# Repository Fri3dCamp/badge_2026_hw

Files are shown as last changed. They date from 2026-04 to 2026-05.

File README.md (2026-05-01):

# Badge 2026 hardware
In deze Git repository kan je de ontwerpbestanden en productiedata vinden van de [Fri3d Camp](https://fri3d.be/) 2026 badge. Revisie 02 is de versie die op kamp zal uitgedeeld worden.

Het schema kan je terug vinden in de [revisie 02 map](<Fri3d_2026_Badge_02/OUTPUT/Fri3D Badge 2026_02.PDF>).

De badge is gebouwd rond de **Espressif [ESP32-S3-WROOM-1-N16R8](Datasheets/esp32-s3-wroom-1_wroom-1u_datasheet_en.pdf) module** met :

- 16MB flash 
- 8MB PSRAM. 
- De [ESP32-S3](Datasheets/esp32-s3_datasheet_en.pdf) dual-core Xtensa LX7 microcontroller (geklokt aan 240MHz)
- Wi-Fi (via de ESP32-S3)
- Bluetooth 5 (via de ESP32-S3)

Omdat deze microcontroller zelf een USB interface heeft is er geen nood meer om een USB serial brug te voorzien zoals op de [badge van 2022]( https://github.com/Fri3dCamp/badge-2020) en de [badge van 2018]( https://github.com/Fri3dCamp/badge). 

We hebben de badge ook uitgerust met:

- [6-assige IMU van ST](Datasheets/lsm6dso.pdf) met dank aan [EBV](https://my.avnet.com/ebv/)
- buzzer
- veel drukknoppen
- joystick
- microSD kaart lezer
- prachtige [2” IPS LCD met touchscreen](Datasheets/HXR20062C21.pdf)
- audio in- en uitgang in de vorm van een 3.5mm TRRS jack
- [extra microcontroller](Datasheets/CH32X035DS0.PDF) voor meer IO
- optionele [LoRa module](https://www.seeedstudio.com/Wio-SX1262-Wireless-Module-without-IPEX-Tape-Reel-p-6417.html)

Er is opnieuw een [tweede voeding](Datasheets/xc6210.pdf) geplaatst om de Wi-Fi module afzonderlijk van voeding te voorzien. Om energie te besparen kan je deze uitschakelen, enkel de ESP32-S3 en de board controller zullen dan nog stroom krijgen. 

Om het geheel van stroom te voorzien gebruiken we deze keer een [2000mAh lithium polymeer cel](Datasheets/2000mAh_704060_battery_Tewaycell.pdf) met een ingebouwd beschermingscircuit. Deze batterijen zijn mechanisch niet zo sterk als de 18650 cellen die we in vorige editie gebruikten, daarom heeft de badge standaard een cover om de batterij te beschermen. 

Om de batterij op te laden via de ingebouwde USB-C poort, maken we opnieuw gebruik van de [TP4056 lineaire lader](Datasheets/TP4056.pdf). 

Er is ook een aansluiting voor de [blaster van 2024]( https://github.com/Fri3dCamp/blaster_2024) ([die van 2022]( https://github.com/Fri3dCamp/timeblaster-2020) is ook compatibel met deze badge!). 

We hebben plek voorzien voor een [SAO header]( https://hackaday.com/2019/03/20/introducing-the-shitty-add-on-v1-69bis-standard/) en is er onderaan een eigen uitbreidingsconnector waar je makkelijk een draadje in kan steken om te experimenteren.

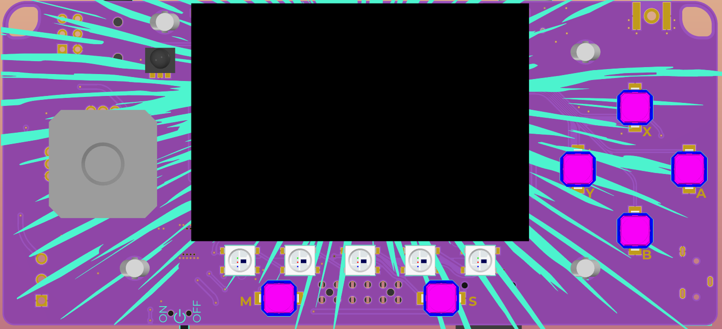
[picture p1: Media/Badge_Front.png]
Badge 2026 02 Front


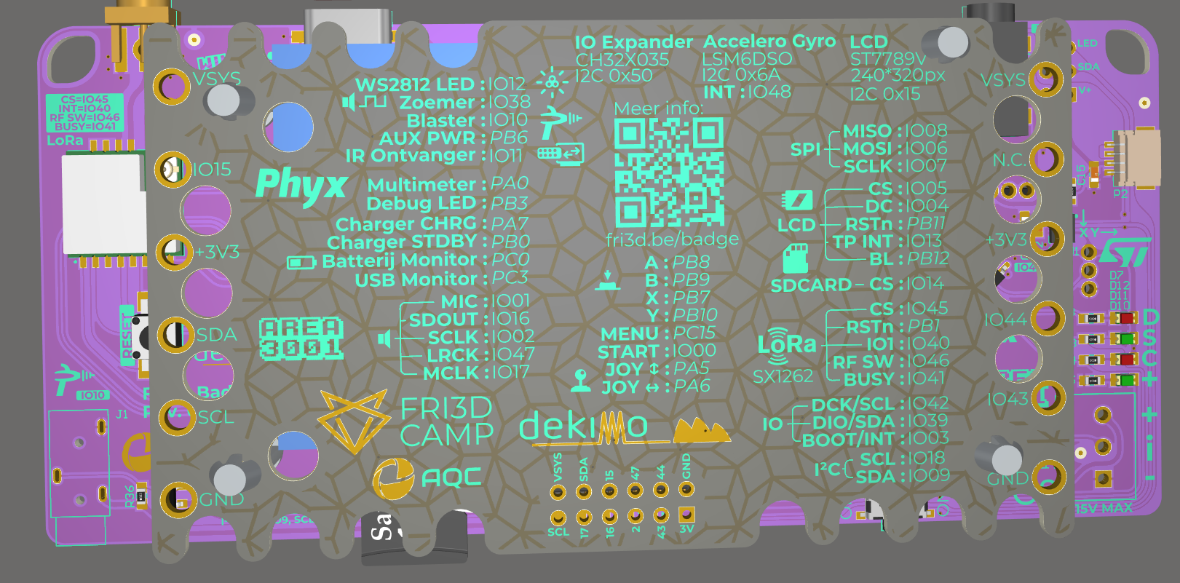
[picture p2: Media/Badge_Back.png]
Badge 2026 02 Back


Voor de liefhebbers heeft Yvan Barbaix ook een 3D model gemaakt om de joystick wat gebruiksvriendelijker te maken. Deze kan je terugvinden in de `Mechanical` map. Verder kan je het 3D model van de badge en cover ook terugvinden in [deze map](Mechanical/).

Het blokschema van de badge geeft tevens een mooi overzicht hoe alles verbonden is met elkaar, dit is een vereenvoudigde weergave van [het schema](<Fri3d_2026_Badge_02/OUTPUT/Fri3D Badge 2026_02.PDF>).

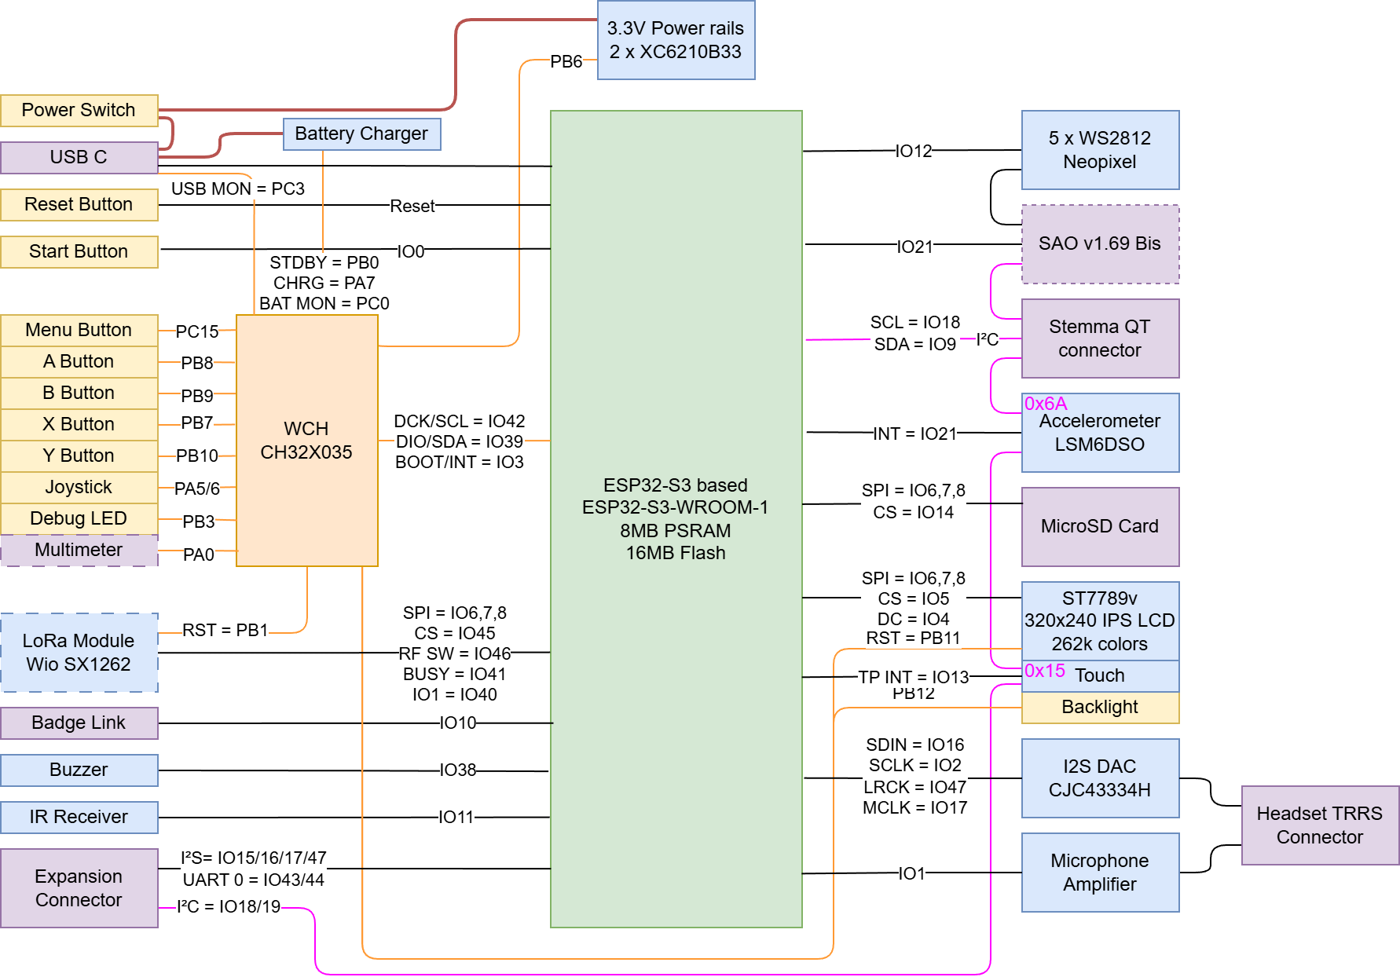
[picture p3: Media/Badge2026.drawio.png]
Badge 2026 02 Block diagram


# Badge 2026 hardware (EN)
This repository contains the hardware design and production files for the [Fri3d Camp](https://fri3d.be/en/) 2024 badge.
Revision 02 will be handed out during the event.

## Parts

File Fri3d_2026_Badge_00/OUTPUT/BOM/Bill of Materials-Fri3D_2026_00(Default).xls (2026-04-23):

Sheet: BOM Report
Bill of Materials |  |  | Fri3D Badge 2026
Project: |  | Fri3D_2026_00.PrjPcb
Revision: |  | 00
Variant: |  | Default
Creation Date: | 19/12/2025 | 22:16
Print Date: | 2026-01-17 | 22:17:15
Footprint | Comment | LibRef | Designator | Value | Description | Supplier 1 | Supplier Part Number 1 | Supplier 2 | Supplier Part Number 2 | Supplier 3 | Supplier Part Number 3 | Quantity
CUI_CMT-1203-SMT | 12x12x3mm Piezo Buzzer Transducer 81dB | BUZ # CUI CMT-1203-SMT | BUZ1 | CMT-1203-SMT | BUZ # CUI CMT-1203-SMT | Digi-key | 102-2197-1-ND | LCSC | C409829 | LCSC | C391037 | 1
C0805_N |  | CAP # 10uF 10V 0805 | C1, C10, C16, C17, C23, C24, C25 | 10uF 10V | CAP # 10uF 10V 0805 | Farnell | 2320859 | LCSC | C17024 | Generic | 10uF 10V 0805 X7R | 7
C0603_N |  | CAP # 100nF 16V 0603 | C2, C4, C6, C8, C9, C14, C15, C22 | 100nF 16V | CAP # 100nF 16V 0603 | LCSC | C282519 |  |  | Generic | 100nF 16V 0603 X7R | 8
C0603_N |  | CAP # 1uF 16V 0603 | C5, C11, C12, C13, C18, C20, C21 | 1uF 16V | CAP # 1uF 16V 0603 | Farnell | 2320814 | LCSC | C1592 | Generic | 1uF 16V 0603 X7R | 7
LED_5050_WS2812B_WHITE | WS2812 based digital RGB LED 5050 White package reduced current | LED # RGB WS2812C-5050 WH | D1, D2, D3, D4, D5 | WS218C 5050 WH | LED # RGB WS2812C-5050 WH | Aliexpress | WS2812C Black 5050 | LCSC | C114587 |  |  | 5
LED_0805_RD | Default 0805 Red LED | LED # Red 0805 | D7, D11 |  | LED # Red 0805 | Farnell | 2099236 | LCSC | C965812 |  |  | 2
LED_0805_GR | Default 0805 Green LED | LED # Green 0805 | D10, D12 |  | LED # Green 0805 | Farnell | 2099239 | LCSC | C965815 |  |  | 2
DO-214AC_AC | 40V 2A 550mV@2A DO-214 Schottky | Schottky # SS24-MS | D13 | SS24-MS | Schottky # SS24-MS | LCSC | C2836395 |  |  |  |  | 1
CHAU_ZIRM-5042B-42-Z2 | ZIRM-5042B-42-Z2 Infrared Receiver 38 kHz 45° 2.7-5.5V 940nm | PHO # IR Rx 940nm ZIRM-5042B-42-Z2 | D15 | ZIRM-5042B-42-Z2 | PHO # IR Rx 940nm ZIRM-5042B-42-Z2 | LCSC | C575386 |  |  |  |  | 1
XUNPU-TYPEC-304S-ACP16 | USB 2.0 C Reversible Receptacle Horizontal full SMD | USB # C 2.0 RCPT TYPEC-304S-ACP16 | J2 | TYPEC-304S-ACP16 | USB # C 2.0 RCPT TYPEC-304S-ACP16 | LCSC | C5187472 | LCSC | C2927040 | LCSC | C5156603 | 1
TFP09-2-12B | Micro SD PiPo Push-Push | MicroSD TFP09-2-12B Push-Push | J3 | TFP09-2-12B | MicroSD TFP09-2-12B Push-Push | AliExpress | TFP09-2-12B | LCSC | C393941 | LCSC | C381082 | 1
HC-PJ-313E8-B-SMT | 3.5mm jack, black, 4 contacts | AUDIO JACK # 3.5 4c HC-PJ-313E8-B-SMT | J4 | HC-PJ-313E8-B-SMT | AUDIO JACK # 3.5 4c HC-PJ-313E8-B-SMT | LCSC | C7501803 |  |  |  |  | 1
WE_709622400 | HIWA LCC-12 Snap-in - Snap-in 12.7mm | SPACER SNAP-SNAP LCC-12 -12.7mm | M1, M2, M3, M4 | LCC-12 | SPACER SNAP-SNAP LCC-12 -12.7mm | LCSC | C155856 |  |  |  |  | 4
FID_0.5mm | Fiducial 0.5mm | Fiducial 0.5mm | M5, M6, M7 | NO BOM | Fiducial 0.5mm | XXX | FOOTPRINT ONLY |  |  |  |  | 3
ESP-ESP32-S3-WROOM-1 | ESP32-S3 based WROOM-1 16MB Flash, 8MB PSRAM | WiFi # MOD ESP32-S3-WROOM-1-N16R8 | MOD1 | ESP32-S3-WROOM-1-N16R8 | WiFi # MOD ESP32-S3-WROOM-1-N16R8 | Espressif | ESP32-S3-WROOM-1-N16R8 | Digi-key | 1965-ESP32-S3-WROOM-1-N16R8DKR-ND |  |  | 1
HRS_FH35C-21S-0.3SHW | FH35C-21S-0.3SHW Top and Bottom Contacts 0.3mm 21pin | ZIF # 0.3mm 21p FH35C-21S-0.3SHW(50) | P1 | FH35C-21S-0.3SHW(50) | ZIF # 0.3mm 21p FH35C-21S-0.3SHW(50) | LCSC | C5242964 | Digi-key | 26-FH35C-21S-0.3SHW(50)CT-ND | LCSC | C48688891 | 1
WE_665104131822 | Header 1.0mm RA Shrouded 4 | HDR # RA SHR 1.0mm 4way - 665104131822 | P2 | 665104131822 | HDR # RA SHR 1.0mm 4way - 665104131822 | Wurth | 665104131822 | Mouser | 710-665104131822 | LCSC | C2905006 | 1
JST_ZH_S2B-ZR-SM4A-TF | Header RA 1.5mm Shrouded S2B-ZR-SM4A-TF | HDR # RA SHR 1.5mm 2way - S2B-ZR-SM4A-TF | P4 | S2B-ZR-SM4A-TF | HDR # RA SHR 1.5mm 2way - S2B-ZR-SM4A-TF | LCSC | C265329 | Farnell | 1830920 | Digi-Key | 455-1693-1-ND | 1
WE_691103110003 | 3 Way Screw HDR 3.5mm Rising Cage | Terminal Block 3.5mm 3way | P5 |  | Terminal Block 3.5mm 3way | LCSC | C784941 | Würth | 691214110003 |  |  | 1
PSP_Mini_Joystick | PSP Mini Joystick | JOY # PSP Mini Joystick | P7 | PSP Mini Joystick | JOY # PSP Mini Joystick | AliExpress | 32958017132 | TaoBao | 606257885046 |  |  | 1
WE_610312243021_POST | Receptacle 6x2 SMD low profile | Receptacle # 2.54mm dual row 12way 610312243021 | P10 | 610312243021 | Receptacle # 2.54mm dual row 12way 610312243021 | Wurth | 610312243021 | Mouser | 710-610312243021 |  |  | 1
R0603_N |  | RES # 10K 0603 | R1, R14, R15, R18, R19, R20, R30, R32, R40 | 10K | RES # 10K 0603 | Farnell | 2502397 | LCSC | C25804 | Generic | 10K 1% 0603 | 9
R0603_N |  | RES # 5K1 0603 | R2, R4, R7, R8, R9, R10, R16, R21, R23, R24, R35, R36, R37, R38, R41, R42, R50, R51 | 5K1 | RES # 5K1 0603 | Farnell | 2845922 | LCSC | C112314 | Generic | 5K1 1% 0603 | 18
R0603_N |  | RES # 100K 0603 | R3, R5, R12, R17, R25, R26, R28, R29, R33, R34 | 100K | RES # 100K 0603 | LCSC | C25803 | LCSC | C14675 | Generic | 100K 1% 0603 | 10
R0603_N |  | RES # 100R 0603 | R6, R43, R46 | 100R | RES # 100R 0603 | Farnell | 2446544 | LCSC | C22775 | Generic | 100R 1% 0603 | 3
R0603_N |  | RES # 1K5 0603 | R11, R13, R22, R31, R39 | 1K5 | RES # 1K5 0603 | LCSC | C2930050 | LCSC | C114668 | Generic | 1K5 1% 0603 | 5
R0402 |  | NTC # 10K 0402 | R27 | 10K | NTC # 10K 0402 | LCSC | C209959 | LCSC | C98099 |  |  | 1
R0603_N |  | RES # 0R 0603 | R47, R48, R49 | 0R | RES # 0R 0603 | Farnell | 2447743 | LCSC | C95177 / C15402 | Generic | 0R 1% 0603 | 3
WE_450404015514 | WS-SLSU Mini slide switch 1P2T SMD | SW # 1P2T WS-SLSU mini slide 6,7 x 2,7 mm | SW4 | 450404015514 | SW # 1P2T WS-SLSU mini slide 6,7 x 2,7 mm | Digi-key | 732-13665-1-ND | LCSC | C431540 |  |  | 1
ALPS_SKPMAME010 | SKPMAME010 6x6 TACTG Switch | SW # TACT ALPS SKPMAME010 | SW5, SW6, SW7, SW8, SW9, SW10 | SKPMAME010 | SW # TACT ALPS SKPMAME010 | LCSC | C115348 | Farnell | 2056804 | Mouser | 688-SKPMAM | 6
WE_430181038816 | 4.5x4.5mm tact SMD H3,8mm | SW # TACT small 4.5x4.5mm SMD WS-TASV | SW11 | 430181038816 | SW # TACT small 4.5x4.5mm SMD WS-TASV | Wurth | 430181038816 | Mouser | 710-430181038816 | LCSC | C174049 | 1
SOT23-3 | 0.2A N-Ch MOSFET Vgs 3.2 | BSS138 N-Ch MOSFET 0.2A 3.2Vgs 60Vds | T1, T2, T9 | BSS138 |  | Farnell | 2432717 |  |  |  |  | 3
SOT23-3 | -2.3A -20V P-Ch MOSFET Vgs -1V | SL2301 P-Ch MOSFET -2.3A -20Vds | T6, T7 | SL2301 | SL2301 P-Ch MOSFET -2.3A -20Vds | LCSC | C181086 |  |  |  |  | 2
STM_LGA14_2.5x3 | Acceleration ±2, ±4, ±8, ±16g Gyro ±125, ±250, ±500, ±1000, ±2000dps | ACCELERO GYRO # LSM6DSOTR-C | U1 | LSM6DSOTR-C | ACCELERO GYRO # LSM6DSOTR-C | LCSC | C2655100 | Mouser | 511-LSM6DSOTR | EBV | LSM6DSOTR | 1
QFN_28_4.0x4.0_P0.4 | WCH CH32X035G8U6 QFN28 RISC-V 32-bit MCU, 62KB Flash, 10KB RAM, USB PD | RISCV # CH32X035G8U6 | U2 | CH32X035G8U6 | RISCV # CH32X035G8U6 | LCSC | C7437027 |  |  |  |  | 1
SOIC_N_8 | I²S 24bit 192kHz 3V~3.6V DAC | DAC # I2S CJC4334H | U4 | CJC4334H | DAC # I2S CJC4334H | LCSC | C41417670 |  |  |  |  | 1
SOIC_N_8_TH | Single Cell LiIon charger max 1A | CHG # TP4056 LiIon 1A | U5 | TP4056 | CHG # TP4056 LiIon 1A | Aliexpress | TP4056 | LCSC | C382139 |  |  | 1
SOT23-5 | 3V3 LDO 700mA 50mV | LDO # 3V3 XC6210B33 | U6, U7 | XC6210B332MR | LDO # 3V3 XC6210B33 | Farnell | 1057803 | LCSC | C47719 |  |  | 2
TI_DBV_R-PDSO-G5 | Single, 30-V, 1-MHz operational amplifier | OP # LM321 | U8 | LM321 | OP # LM321 | LCSC | C18164494 | LCSC | C51026323 | LCSC | C18723612 | 1
 |  |  |  |  |  |  |  |  |  |  |  | 120
Approved |  | Notes

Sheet: MANUAL
LibRef | Designator | Description | QTY | 10
BUZ # CUI CMT-1203-SMT | BUZ1 | BUZ # CUI CMT-1203-SMT | 1 | 10
CAP # 10uF 10V 0805 | C1, C10, C16, C17, C23, C24, C25 | CAP # 10uF 10V 0805 | 7 | 70
CAP # 100nF 16V 0603 | C2, C4, C6, C8, C9, C14, C15, C22 | CAP # 100nF 16V 0603 | 8 | 80
CAP # 1uF 16V 0603 | C5, C11, C12, C13, C18, C20, C21 | CAP # 1uF 16V 0603 | 7 | 70
LED # RGB WS2812C-5050 WH | D1, D2, D3, D4, D5 | LED # RGB WS2812C-5050 WH | 5 | 50
LED # Red 0805 | D7, D11 | LED # Red 0805 | 2 | 20
LED # Green 0805 | D10, D12 | LED # Green 0805 | 2 | 20
Schottky # SS24-MS | D13 | Schottky # SS24-MS | 1 | 10
PHO # IR Rx 940nm ZIRM-5042B-42-Z2 | D15 | PHO # IR Rx 940nm ZIRM-5042B-42-Z2 | 1 | 10
USB # C 2.0 RCPT TYPEC-304S-ACP16 | J2 | USB # C 2.0 RCPT TYPEC-304S-ACP16 | 1 | 10
MicroSD # TFP09-2-12B Push-Push | J3 | MicroSD # TFP09-2-12B Push-Push | 1 | 10
AUDIO JACK # 3.5 4c HC-PJ-313E8-B-SMT | J4 | AUDIO JACK # 3.5 4c HC-PJ-313E8-B-SMT | 1 | 10
WiFi # MOD ESP32-S3-WROOM-1-N16R8 | MOD1 | WiFi # MOD ESP32-S3-WROOM-1-N16R8 | 1 | 10
ZIF # 0.3mm 21p FH35C-21S-0.3SHW(50) | P1 | ZIF # 0.3mm 21p FH35C-21S-0.3SHW(50) | 1 | 10
HDR # RA SHR 1.0mm 4way - 665104131822 | P2 | HDR # RA SHR 1.0mm 4way - 665104131822 | 1 | 10
HDR # RA SHR 1.5mm 2way - S2B-ZR-SM4A-TF | P4 | HDR # RA SHR 1.5mm 2way - S2B-ZR-SM4A-TF | 1 | 10
Terminal Block 3.5mm 3way | P5 | Terminal Block 3.5mm 3way | 1 | 10
JOY PSP Mini Joystick | P7 | JOY PSP Mini Joystick | 1 | 10
Receptacle # 2.54mm dual row 12way 610312243021 | P10 | Receptacle # 2.54mm dual row 12way 610312243021 | 1 | 10
RES # 10K 0603 | R1, R14, R15, R18, R19, R20, R30, R32, R40 | RES # 10K 0603 | 9 | 90
RES # 5K1 0603 | R2, R4, R7, R8, R9, R10, R16, R21, R23, R24, R35, R36, R37, R38, R41, R42, R50, R51 | RES # 5K1 0603 | 18 | 180
RES # 100K 0603 | R3, R5, R12, R17, R25, R26, R28, R29, R33, R34 | RES # 100K 0603 | 10 | 100
RES # 100R 0603 | R6, R43, R46 | RES # 100R 0603 | 3 | 30
RES # 1K5 0603 | R11, R13, R22, R31, R39 | RES # 1K5 0603 | 5 | 50
NTC # 10K 0402 | R27 | NTC # 10K 0402 | 1 | 10
RES # 0R 0603 | R47, R48, R49 | RES # 0R 0603 | 3 | 30
SW # 1P2T WS-SLSU mini slide 6,7 x 2,7 mm | SW4 | SW # 1P2T WS-SLSU mini slide 6,7 x 2,7 mm | 1 | 10
SW # TACT ALPS SKPMAME010 | SW5, SW6, SW7, SW8, SW9, SW10 | SW # TACT ALPS SKPMAME010 | 6 | 60
SW # TACT small 4.5x4.5mm SMD WS-TASV | SW11 | SW # TACT small 4.5x4.5mm SMD WS-TASV | 1 | 10
BSS138 N-Ch MOSFET 0.2A 3.2Vgs 60Vds | T1, T2, T9 |  | 3 | 30
SL2301 P-Ch MOSFET -2.3A -20Vds | T6, T7 | SL2301 P-Ch MOSFET -2.3A -20Vds | 2 | 20
ACCELERO GYRO # LSM6DSOTR-C | U1 | ACCELERO GYRO # LSM6DSOTR-C | 1 | 10
RISCV # CH32X035G8U6 | U2 | RISCV # CH32X035G8U6 | 1 | 10
DAC # I2S CJC4334H | U4 | DAC # I2S CJC4334H | 1 | 10
CHG # TP4056 LiIon 1A | U5 | CHG # TP4056 LiIon 1A | 1 | 10
LDO # 3V3 XC6210B33 | U6, U7 | LDO # 3V3 XC6210B33 | 2 | 20
OP # LM321 | U8 | OP # LM321 | 1 | 10

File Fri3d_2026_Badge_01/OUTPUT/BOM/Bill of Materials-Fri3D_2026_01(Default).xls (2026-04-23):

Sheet: BOM Report
Bill of Materials |  |  | Fri3D Badge 2026
Project: |  | Fri3D_2026_01.PrjPcb
Revision: |  | 01
Variant: |  | Default
Creation Date: | 01/03/2026 | 01:36
Print Date: | 2026-03-18 | 19:20:01
Footprint | Comment | LibRef | Designator | Value | Description | Supplier 1 | Supplier Part Number 1 | Supplier 2 | Supplier Part Number 2 | Supplier 3 | Supplier Part Number 3 | Quantity
CUI_CMT-1203-SMT | 12x12x3mm Piezo Buzzer Transducer 81dB | BUZ # CUI CMT-1203-SMT | BUZ1 | CMT-1203-SMT | BUZ # CUI CMT-1203-SMT | Digi-key | 102-2197-1-ND | LCSC | C409829 | LCSC | C391037 | 1
C0805_N |  | CAP # 10uF 10V 0805 | C1, C10, C16, C17, C23, C24, C25 | 10uF 10V | CAP # 10uF 10V 0805 | Farnell | 2320859 | LCSC | C17024 | Generic | 10uF 10V 0805 X7R | 7
C0603_N |  | CAP # 100nF 16V 0603 | C2, C4, C6, C8, C9, C14, C15, C22 | 100nF 16V | CAP # 100nF 16V 0603 | LCSC | C282519 |  |  | Generic | 100nF 16V 0603 X7R | 8
C0603_N |  | CAP # 1uF 16V 0603 | C5, C11, C12, C13, C18, C20, C21 | 1uF 16V | CAP # 1uF 16V 0603 | Farnell | 2320814 | LCSC | C1592 | Generic | 1uF 16V 0603 X7R | 7
LED_5050_WS2812B_WHITE | WS2812 based digital RGB LED 5050 White package reduced current | LED # RGB WS2812C-5050 WH | D1, D2, D3, D4, D5 | WS218C 5050 WH | LED # RGB WS2812C-5050 WH | Aliexpress | WS2812C Black 5050 | LCSC | C114587 |  |  | 5
LED_0805_RD | Default 0805 Red LED | LED # Red 0805 | D7, D11 |  | LED # Red 0805 | Farnell | 2099236 | LCSC | C965812 |  |  | 2
LED_0805_GR | Default 0805 Green LED | LED # Green 0805 | D10, D12 |  | LED # Green 0805 | Farnell | 2099239 | LCSC | C965815 |  |  | 2
DO-214AC_AC | 40V 2A 550mV@2A DO-214 Schottky | Schottky # SS24-MS | D13 | SS24-MS | Schottky # SS24-MS | LCSC | C2836395 |  |  |  |  | 1
CHAU_ZIRM-5042B-42-Z2 | ZIRM-5042B-42-Z2 Infrared Receiver 38 kHz 45° 2.7-5.5V 940nm | PHO # IR Rx 940nm ZIRM-5042B-42-Z2 | D15 | ZIRM-5042B-42-Z2 | PHO # IR Rx 940nm ZIRM-5042B-42-Z2 | LCSC | C575386 |  |  |  |  | 1
SHOU_HAN_PJ-320A-3P | 3.5mm jack, black, 3 contacts | AUDIO JACK 3.5 3c PJ-320A-3P | J1 | PJ-320A-3P | AUDIO JACK 3.5 3c PJ-320A-3P | LCSC | C17701689 | LCSC | C19189087 |  |  | 1
XUNPU-TYPEC-304S-ACP16 | USB 2.0 C Reversible Receptacle Horizontal full SMD | USB # C 2.0 RCPT TYPEC-304S-ACP16 | J2 | TYPEC-304S-ACP16 | USB # C 2.0 RCPT TYPEC-304S-ACP16 | LCSC | C5187472 | LCSC | C2927040 | LCSC | C5156603 | 1
TFP09-2-12B | Micro SD PiPo Push-Push | MicroSD TFP09-2-12B Push-Push | J3 | TFP09-2-12B | MicroSD TFP09-2-12B Push-Push | AliExpress | TFP09-2-12B | LCSC | C393941 | LCSC | C381082 | 1
CAX_PJ-327F-5PS | 3.5mm jack, black, 4 contacts 15mm | AUDIO JACK # 3.5 4c 15mm PJ-327F-5PS | J4 | PJ-327F-5PS | AUDIO JACK # 3.5 4c 15mm PJ-327F-5PS | LCSC | C50176645 |  |  |  |  | 1
WE_709622400 | HIWA LCC-12 Snap-in - Snap-in 12.7mm | SPACER SNAP-SNAP LCC-12 -12.7mm | M1, M2, M3, M4 | LCC-12 | SPACER SNAP-SNAP LCC-12 -12.7mm | LCSC | C155856 |  |  |  |  | 4
FID_0.5mm | Fiducial 0.5mm | Fiducial 0.5mm | M5, M6, M7 | NO BOM | Fiducial 0.5mm | XXX | FOOTPRINT ONLY |  |  |  |  | 3
ESP-ESP32-S3-WROOM-1 | ESP32-S3 based WROOM-1 16MB Flash, 8MB PSRAM | WiFi # MOD ESP32-S3-WROOM-1-N16R8 | MOD1 | ESP32-S3-WROOM-1-N16R8 | WiFi # MOD ESP32-S3-WROOM-1-N16R8 | Espressif | ESP32-S3-WROOM-1-N16R8 | Digi-key | 1965-ESP32-S3-WROOM-1-N16R8DKR-ND |  |  | 1
SEE_Wio-SX1262 | 868/915MHz 22dBm LoRa Module with Antenna Pin | RF # MOD Wio-SX1262-N 868MHz LoRa ANT pin | MOD2 | Wio-SX1262-N | RF # MOD Wio-SX1262-N 868MHz LoRa ANT pin | Seeed Studio | 113991436 | Digi-key | 1597-113991436-ND |  |  | 1
HRS_FH35C-21S-0.3SHW | FH35C-21S-0.3SHW Top and Bottom Contacts 0.3mm 21pin | ZIF # 0.3mm 21p FH35C-21S-0.3SHW(50) | P1 | FH35C-21S-0.3SHW(50) | ZIF # 0.3mm 21p FH35C-21S-0.3SHW(50) | LCSC | C5242964 | Digi-key | 26-FH35C-21S-0.3SHW(50)CT-ND | LCSC | C48688891 | 1
WE_665104131822 | Header 1.0mm RA Shrouded 4 | HDR # RA SHR 1.0mm 4way - 665104131822 | P2 | 665104131822 | HDR # RA SHR 1.0mm 4way - 665104131822 | Wurth | 665104131822 | Mouser | 710-665104131822 | LCSC | C2905006 | 1
DEA_DL-SMA-K513-08K | DEALON DL-SMA-K513-08K | RF # SMA DL-SMA-K513-08K | P3 | DL-SMA-K513-08K | RF # SMA DL-SMA-K513-08K | LCSC | C4749212 |  |  |  |  | 1
JST_ZH_S2B-ZR-SM4A-TF | Header RA 1.5mm Shrouded S2B-ZR-SM4A-TF | HDR # RA SHR 1.5mm 2way - S2B-ZR-SM4A-TF | P4 | S2B-ZR-SM4A-TF | HDR # RA SHR 1.5mm 2way - S2B-ZR-SM4A-TF | LCSC | C265329 | Farnell | 1830920 | Digi-Key | 455-1693-1-ND | 1
WE_691103110003 | 3 Way Screw HDR 3.5mm Rising Cage | Terminal Block 3.5mm 3way | P5 |  | Terminal Block 3.5mm 3way | LCSC | C784941 | Würth | 691214110003 |  |  | 1
RCPT2X3 | Receptacle 3x2 | Receptacle 2.54mm dual row 6way | P6 |  | Receptacle 2.54mm dual row 6way | LCSC | C92272 | LCSC | C358725 |  |  | 1
PSP_Mini_Joystick | PSP Mini Joystick | JOY # PSP Mini Joystick | P7 | PSP Mini Joystick | JOY # PSP Mini Joystick | AliExpress | 32958017132 | TaoBao | 606257885046 |  |  | 1
WE_610312243021_POST | Receptacle 6x2 SMD low profile | Receptacle # 2.54mm dual row 12way 610312243021 | P10 | 610312243021 | Receptacle # 2.54mm dual row 12way 610312243021 | Wurth | 610312243021 | Mouser | 710-610312243021 |  |  | 1
R0603_N |  | RES # 10K 0603 | R1, R14, R15, R18, R19, R20, R30, R32, R40 | 10K | RES # 10K 0603 | Farnell | 2502397 | LCSC | C25804 | Generic | 10K 1% 0603 | 9
R0603_N |  | RES # 5K1 0603 | R2, R7, R8, R9, R10, R16, R21, R23, R24, R35, R36, R37, R38, R41, R42, R50, R51 | 5K1 | RES # 5K1 0603 | Farnell | 2845922 | LCSC | C112314 | Generic | 5K1 1% 0603 | 17
R0603_N |  | RES # 100K 0603 | R3, R5, R12, R17, R25, R26, R28, R29, R33, R34 | 100K | RES # 100K 0603 | LCSC | C25803 | LCSC | C14675 | Generic | 100K 1% 0603 | 10
R0603_N |  | RES # 100R 0603 | R4, R6, R43, R46 | 100R | RES # 100R 0603 | Farnell | 2446544 | LCSC | C22775 | Generic | 100R 1% 0603 | 4
R0603_N |  | RES # 1K5 0603 | R13, R22, R31, R39 | 1K5 | RES # 1K5 0603 | LCSC | C2930050 | LCSC | C114668 | Generic | 1K5 1% 0603 | 4
R0402 |  | NTC # 10K 0402 | R27 | 10K | NTC # 10K 0402 | LCSC | C209959 | LCSC | C98099 |  |  | 1
WE_450404015514 | WS-SLSU Mini slide switch 1P2T SMD | SW # 1P2T WS-SLSU mini slide 6,7 x 2,7 mm | SW4 | 450404015514 | SW # 1P2T WS-SLSU mini slide 6,7 x 2,7 mm | Digi-key | 732-13665-1-ND | LCSC | C431540 |  |  | 1
ALPS_SKPMAME010 | SKPMAME010 6x6 TACTG Switch | SW # TACT ALPS SKPMAME010 | SW5, SW6, SW7, SW8, SW9, SW10 | SKPMAME010 | SW # TACT ALPS SKPMAME010 | LCSC | C115348 | Farnell | 2056804 | Mouser | 688-SKPMAM | 6
WE_430181038816 | 4.5x4.5mm tact SMD H3,8mm | SW # TACT small 4.5x4.5mm SMD WS-TASV | SW11 | 430181038816 | SW # TACT small 4.5x4.5mm SMD WS-TASV | Wurth | 430181038816 | Mouser | 710-430181038816 | LCSC | C174049 | 1
SOT23-3 | 0.2A N-Ch MOSFET Vgs 3.2 | BSS138 N-Ch MOSFET 0.2A 3.2Vgs 60Vds | T1, T2, T9 | BSS138 |  | Farnell | 2432717 |  |  |  |  | 3
SOT23-3 | -2.3A -20V P-Ch MOSFET Vgs -1V | SL2301 P-Ch MOSFET -2.3A -20Vds | T6, T7 | SL2301 | SL2301 P-Ch MOSFET -2.3A -20Vds | LCSC | C181086 |  |  |  |  | 2
TP_1.5mm_0.9mm |  | TP 1.5mm | TP1 | NO BOM | TP 1.5mm |  |  |  |  |  |  | 1
STM_LGA14_2.5x3 | Acceleration ±2, ±4, ±8, ±16g Gyro ±125, ±250, ±500, ±1000, ±2000dps | ACCELERO GYRO # LSM6DSOTR-C | U1 | LSM6DSOTR-C | ACCELERO GYRO # LSM6DSOTR-C | LCSC | C2655100 | Mouser | 511-LSM6DSOTR | EBV | LSM6DSOTR | 1
QFN_28_4.0x4.0_P0.4 | WCH CH32X035G8U6 QFN28 RISC-V 32-bit MCU, 62KB Flash, 10KB RAM, USB PD | RISCV # CH32X035G8U6 | U2 | CH32X035G8U6 | RISCV # CH32X035G8U6 | LCSC | C7437027 |  |  |  |  | 1
SOIC_N_8 | I²S 24bit 192kHz 3V~3.6V DAC | DAC # I2S CJC4334H | U4 | CJC4334H | DAC # I2S CJC4334H | LCSC | C41417670 |  |  |  |  | 1
SOIC_N_8_TH | Single Cell LiIon charger max 1A | CHG # TP4056 LiIon 1A | U5 | TP4056 | CHG # TP4056 LiIon 1A | Aliexpress | TP4056 | LCSC | C382139 |  |  | 1
SOT23-5 | 3V3 LDO 700mA 50mV | LDO # 3V3 XC6210B33 | U6, U7 | XC6210B332MR | LDO # 3V3 XC6210B33 | Farnell | 1057803 | LCSC | C47719 |  |  | 2
TI_DBV_R-PDSO-G5 | Single, 30-V, 1-MHz operational amplifier | OP # LM321 | U8 | LM321 | OP # LM321 | LCSC | C18164494 | LCSC | C51026323 | LCSC | C18723612 | 1
 |  |  |  |  |  |  |  |  |  |  |  | 121
Approved |  | Notes

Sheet: Print
Footprint | Designator | Description | Quantity
CUI_CMT-1203-SMT | BUZ1 | BUZ # CUI CMT-1203-SMT | 1
C0805_N | C1, C10, C16, C17, C23, C24, C25 | CAP # 10uF 10V 0805 | 7
C0603_N | C2, C4, C6, C8, C9, C14, C15, C22 | CAP # 100nF 16V 0603 | 8
C0603_N | C5, C11, C12, C13, C18, C20, C21 | CAP # 1uF 16V 0603 | 7
LED_5050_WS2812B_WHITE | D1, D2, D3, D4, D5 | LED # RGB WS2812C-5050 WH | 5
LED_0805_RD | D7, D11 | LED # Red 0805 | 2
LED_0805_GR | D10, D12 | LED # Green 0805 | 2
DO-214AC_AC | D13 | Schottky # SS24-MS | 1
CHAU_ZIRM-5042B-42-Z2 | D15 | PHO # IR Rx 940nm ZIRM-5042B-42-Z2 | 1
SHOU_HAN_PJ-320A-3P | J1 | AUDIO JACK 3.5 3c PJ-320A-3P | 1
XUNPU-TYPEC-304S-ACP16 | J2 | USB # C 2.0 RCPT TYPEC-304S-ACP16 | 1
TFP09-2-12B | J3 | MicroSD TFP09-2-12B Push-Push | 1
CAX_PJ-327F-5PS | J4 | AUDIO JACK # 3.5 4c 15mm PJ-327F-5PS | 1
WE_709622400 | M1, M2, M3, M4 | SPACER SNAP-SNAP LCC-12 -12.7mm | 4
FID_0.5mm | M5, M6, M7 | Fiducial 0.5mm | 3
ESP-ESP32-S3-WROOM-1 | MOD1 | WiFi # MOD ESP32-S3-WROOM-1-N16R8 | 1
SEE_Wio-SX1262 | MOD2 | RF # MOD Wio-SX1262-N 868MHz LoRa ANT pin | 1
HRS_FH35C-21S-0.3SHW | P1 | ZIF # 0.3mm 21p FH35C-21S-0.3SHW(50) | 1
WE_665104131822 | P2 | HDR # RA SHR 1.0mm 4way - 665104131822 | 1
DEA_DL-SMA-K513-08K | P3 | RF # SMA DL-SMA-K513-08K | 1
JST_ZH_S2B-ZR-SM4A-TF | P4 | HDR # RA SHR 1.5mm 2way - S2B-ZR-SM4A-TF | 1
WE_691103110003 | P5 | Terminal Block 3.5mm 3way | 1
RCPT2X3 | P6 | Receptacle 2.54mm dual row 6way | 1
PSP_Mini_Joystick | P7 | JOY # PSP Mini Joystick | 1
WE_610312243021_POST | P10 | Receptacle # 2.54mm dual row 12way 610312243021 | 1
R0603_N | R1, R14, R15, R18, R19, R20, R30, R32, R40 | RES # 10K 0603 | 9
R0603_N | R2, R7, R8, R9, R10, R16, R21, R23, R24, R35, R36, R37, R38, R41, R42, R50, R51 | RES # 5K1 0603 | 17
R0603_N | R3, R5, R12, R17, R25, R26, R28, R29, R33, R34 | RES # 100K 0603 | 10
R0603_N | R4, R6, R43, R46 | RES # 100R 0603 | 4
R0603_N | R13, R22, R31, R39 | RES # 1K5 0603 | 4
R0402 | R27 | NTC # 10K 0402 | 1
WE_450404015514 | SW4 | SW # 1P2T WS-SLSU mini slide 6,7 x 2,7 mm | 1
ALPS_SKPMAME010 | SW5, SW6, SW7, SW8, SW9, SW10 | SW # TACT ALPS SKPMAME010 | 6
WE_430181038816 | SW11 | SW # TACT small 4.5x4.5mm SMD WS-TASV | 1
SOT23-3 | T1, T2, T9 |  | 3
SOT23-3 | T6, T7 | SL2301 P-Ch MOSFET -2.3A -20Vds | 2
TP_1.5mm_0.9mm | TP1 | TP 1.5mm | 1
STM_LGA14_2.5x3 | U1 | ACCELERO GYRO # LSM6DSOTR-C | 1
QFN_28_4.0x4.0_P0.4 | U2 | RISCV # CH32X035G8U6 | 1
SOIC_N_8 | U4 | DAC # I2S CJC4334H | 1
SOIC_N_8_TH | U5 | CHG # TP4056 LiIon 1A | 1
SOT23-5 | U6, U7 | LDO # 3V3 XC6210B33 | 2
TI_DBV_R-PDSO-G5 | U8 | OP # LM321 | 1

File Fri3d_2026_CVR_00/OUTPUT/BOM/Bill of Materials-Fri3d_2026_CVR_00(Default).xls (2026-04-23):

Bill of Materials |  |  | Fri3D Badge 2026 CVR
Project: |  | Fri3d_2026_CVR_00.PrjPcb
Revision: |  | 00
Variant: |  | Default
Creation Date: | 17/04/2026 | 22:50
Print Date: | 2026-04-17 | 22:50:30
Footprint | Comment | LibRef | Designator | #Column Name Error:' Value | Description | #Column Name Error:' Supplier 1 | #Column Name Error:' Supplier Part Number 1 | #Column Name Error:' Supplier 2 | #Column Name Error:' Supplier Part Number 2 | #Column Name Error:' Supplier 3 | #Column Name Error:' Supplier Part Number 3 | Quantity
 |  |  |  |  |  |  |  |  |  |  |  | 0
Approved |  | Notes

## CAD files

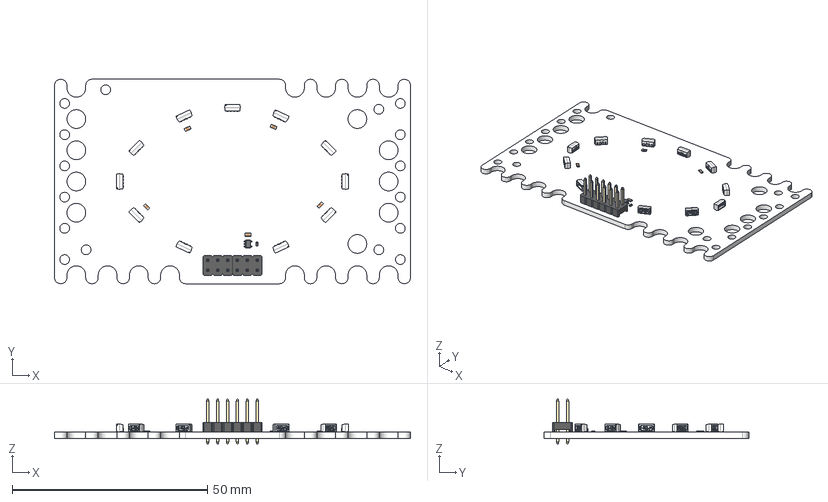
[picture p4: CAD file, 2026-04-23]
Mechanical/Fri3d_2026_CVR_00.step
91.2 x 52.4 x 11.5 mm
R0402
LED4020-ZAO x 44
LED4020-BDT x 11
LED4020 x 11
XIN-L0_2MM-CR x 11
XIN-L0_1X0_2MM-CG x 11
XIN-L0_1X0_2MM-CB x 11
C0603 x 5
User Library-SC70-5-1
HDR_2x3 x 2

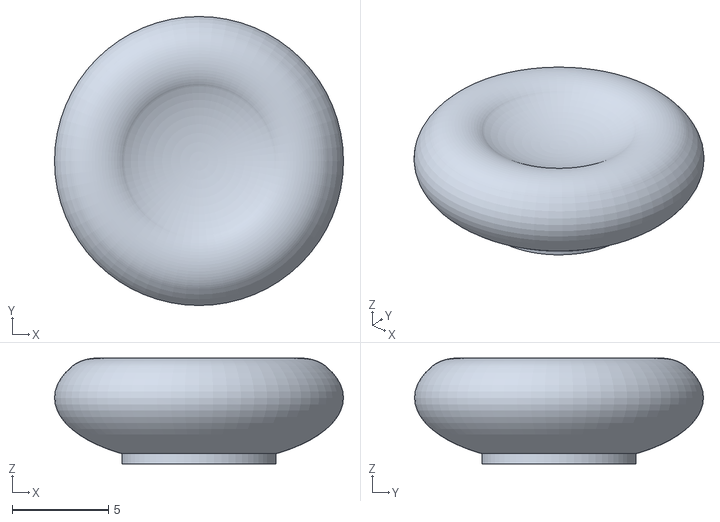
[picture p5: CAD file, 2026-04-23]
Mechanical/joystick.stl
15.0 x 15.0 x 5.50

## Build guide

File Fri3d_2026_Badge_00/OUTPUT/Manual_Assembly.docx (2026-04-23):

BADGE 2026 REV.00

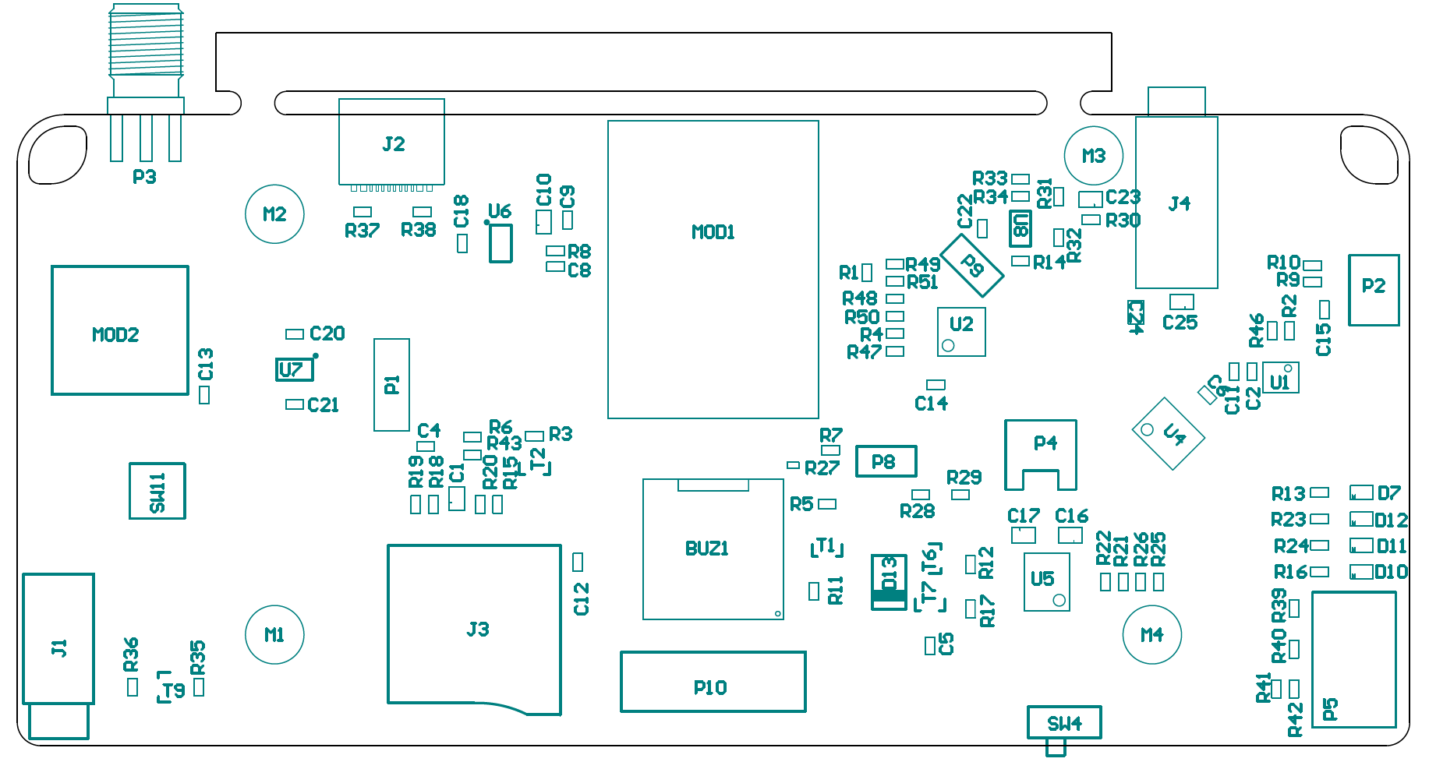
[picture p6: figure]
Afbeelding met tekst, diagram, Plan, schematisch Door AI gegenereerde inhoud is mogelijk onjuist.
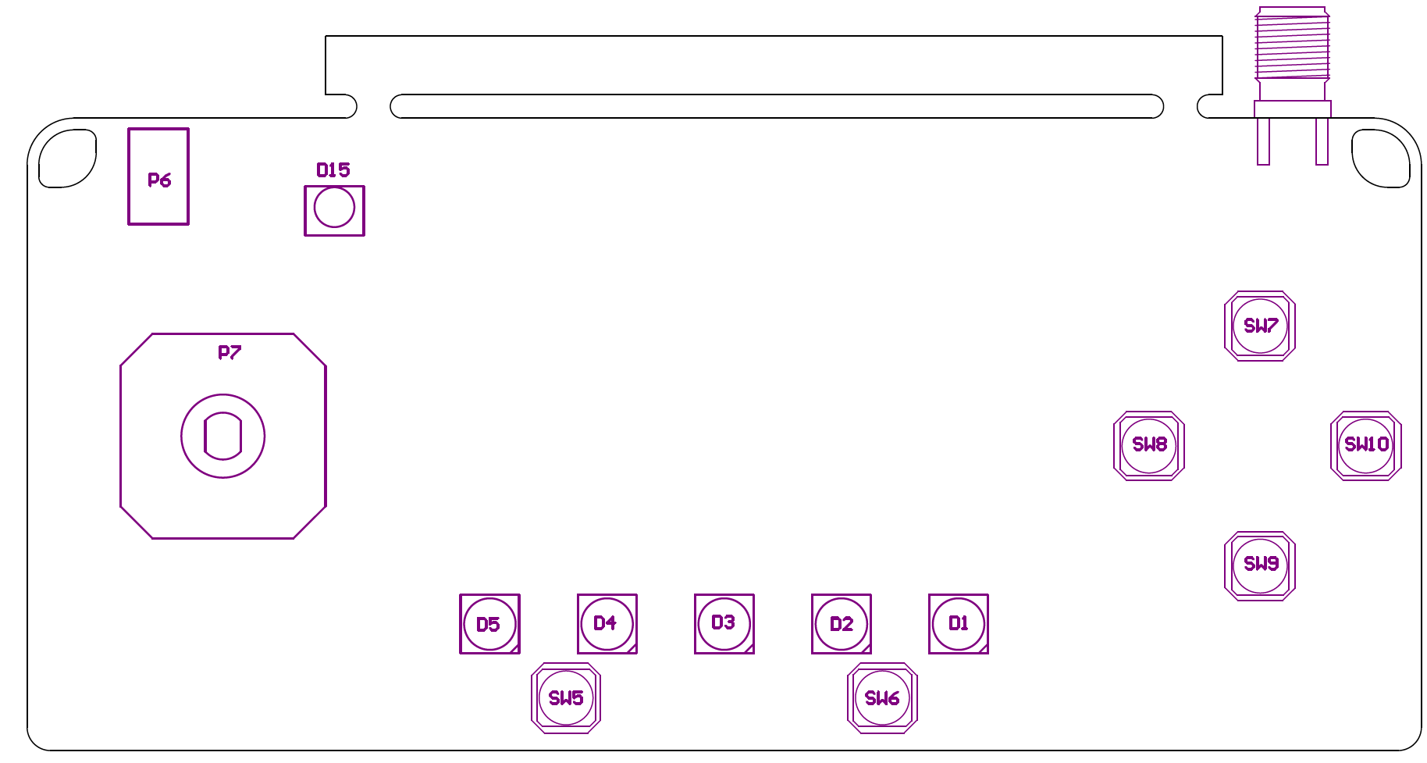
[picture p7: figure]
Afbeelding met tekst, diagram, schermopname, Rechthoek Door AI gegenereerde inhoud is mogelijk onjuist.

LibRef | Designator | Description | QTY | 10
BUZ # CUI CMT-1203-SMT | BUZ1 | BUZ # CUI CMT-1203-SMT | 1 | 10
CAP # 10uF 10V 0805 | C1, C10, C16, C17, C23, C24, C25 | CAP # 10uF 10V 0805 | 7 | 70
CAP # 100nF 16V 0603 | C2, C4, C6, C8, C9, C14, C15, C22 | CAP # 100nF 16V 0603 | 8 | 80
CAP # 1uF 16V 0603 | C5, C11, C12, C13, C18, C20, C21 | CAP # 1uF 16V 0603 | 7 | 70
LED # RGB WS2812C-5050 WH | D1, D2, D3, D4, D5 | LED # RGB WS2812C-5050 WH | 5 | 50
LED # Red 0805 | D7, D11 | LED # Red 0805 | 2 | 20
LED # Green 0805 | D10, D12 | LED # Green 0805 | 2 | 20
Schottky # SS24-MS | D13 | Schottky # SS24-MS | 1 | 10
PHO # IR Rx 940nm ZIRM-5042B-42-Z2 | D15 | PHO # IR Rx 940nm ZIRM-5042B-42-Z2 | 1 | 10
USB # C 2.0 RCPT TYPEC-304S-ACP16 | J2 | USB # C 2.0 RCPT TYPEC-304S-ACP16 | 1 | 10
MicroSD # TFP09-2-12B Push-Push | J3 | MicroSD # TFP09-2-12B Push-Push | 1 | 10
AUDIO JACK # 3.5 4c HC-PJ-313E8-B-SMT | J4 | AUDIO JACK # 3.5 4c HC-PJ-313E8-B-SMT | 1 | 10
WiFi # MOD ESP32-S3 | MOD1 | WiFi # MOD ESP32-S3-WROOM | 1 | 10
ZIF # 0.3mm 21p FH35C-21S-0.3SHW(50) | P1 | ZIF # 0.3mm 21p FH35C-21S-0.3SHW(50) | 1 | 10
HDR # RA SHR 1.0mm 4way | P2 | HDR # RA SHR 1.0mm 4way - 665104131822 | 1 | 10
HDR # RA SHR 1.5mm 2way | P4 | HDR # RA SHR 1.5mm 2way - S2B-ZR-SM4A-TF | 1 | 10
TB 3.5mm 3way | P5 | Terminal Block 3.5mm 3way | 1 | 10
JOY PSP Mini Joystick | P7 | JOY PSP Mini Joystick | 1 | 10
Receptacle # 2.54mm dual row 12way 610312243021 | P10 | Receptacle # 2.54mm dual row 12way 610312243021 | 1 | 10
RES # 10K 0603 | R1, R14, R15, R18, R19, R20, R30, R32, R40 | RES # 10K 0603 | 9 | 90
RES # 5K1 0603 | R2, R4, R7, R8, R9, R10, R16, R21, R23, R24, R35, R36, R37, R38, R41, R42, R50, R51 | RES # 5K1 0603 | 18 | 180
RES # 100K 0603 | R3, R5, R12, R17, R25, R26, R28, R29, R33, R34 | RES # 100K 0603 | 10 | 100
RES # 100R 0603 | R6, R43, R46 | RES # 100R 0603 | 3 | 30
RES # 1K5 0603 | R11, R13, R22, R31, R39 | RES # 1K5 0603 | 5 | 50
NTC # 10K 0402 | R27 | NTC # 10K 0402 | 1 | 10
RES # 0R 0603 | R47, R48, R49 | RES # 0R 0603 | 3 | 30
SW # 1P2T WS-SLSU mini slide 6,7 x 2,7 mm | SW4 | SW # 1P2T WS-SLSU mini slide 6,7 x 2,7 mm | 1 | 10
SW # TACT ALPS SKPMAME010 | SW5, SW6, SW7, SW8, SW9, SW10 | SW # TACT ALPS SKPMAME010 | 6 | 60
SW # TACT small 4.5x4.5mm | SW11 | SW # TACT small 4.5x4.5mm SMD WS-TASV | 1 | 10
BSS138 N-Ch MOSFET 0.2A 3.2Vgs 60Vds | T1, T2, T9 | | 3 | 30
SL2301 P-Ch MOSFET -2.3A -20Vds | T6, T7 | SL2301 P-Ch MOSFET -2.3A -20Vds | 2 | 20
ACCELERO GYRO # LSM6DSOTR-C | U1 | ACCELERO GYRO # LSM6DSOTR-C | 1 | 10
RISCV # CH32X035G8U6 | U2 | RISCV # CH32X035G8U6 | 1 | 10
DAC # I2S CJC4334H | U4 | DAC # I2S CJC4334H | 1 | 10
CHG # TP4056 LiIon 1A | U5 | CHG # TP4056 LiIon 1A | 1 | 10
LDO # 3V3 XC6210B33 | U6, U7 | LDO # 3V3 XC6210B33 | 2 | 20
OP # LM321 | U8 | OP # LM321 | 1 | 10

DJ-ADDON 2026 REV.00

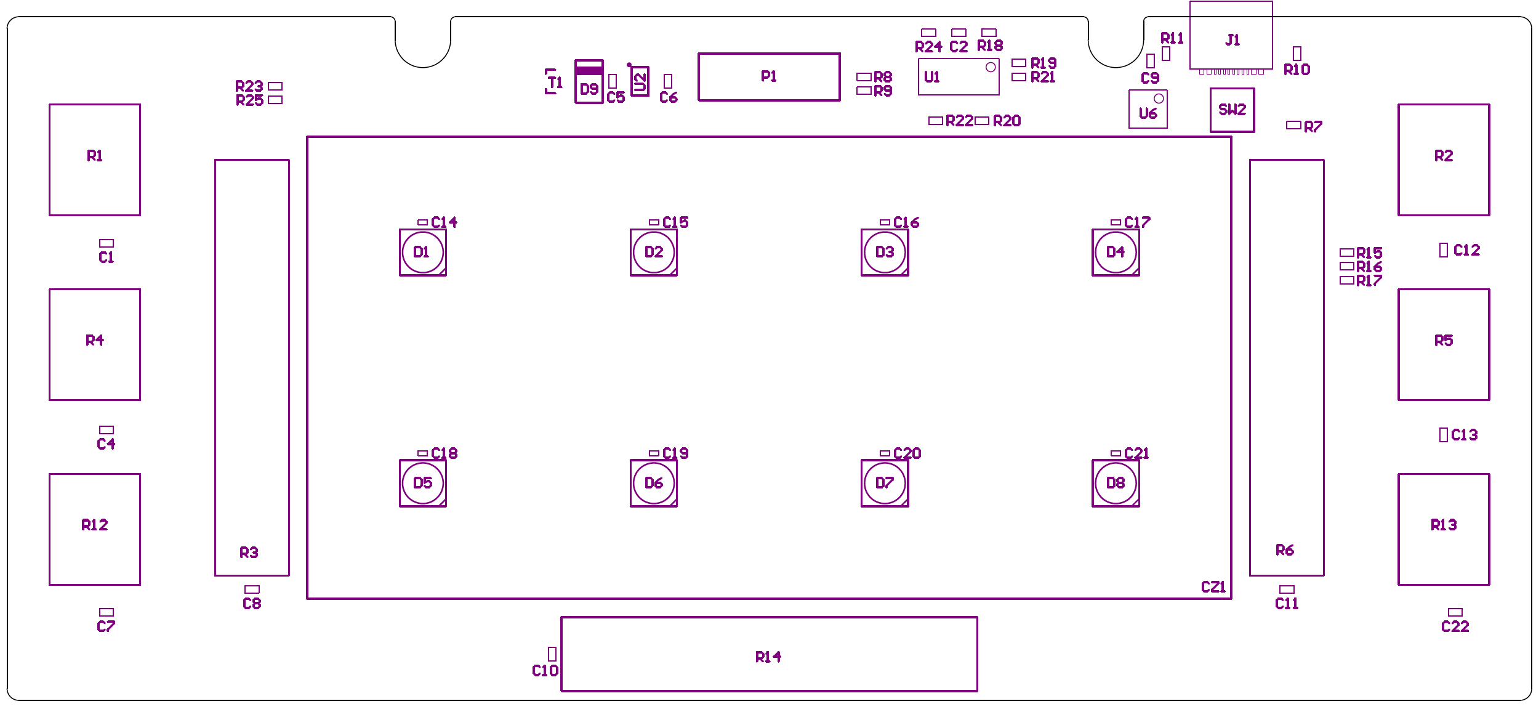
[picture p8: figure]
Afbeelding met diagram, tekst, Rechthoek, Plan Door AI gegenereerde inhoud is mogelijk onjuist.

LibRef | Designator | Description | QTY | 5
CAP # 100nF 16V 0603 | C2, C9 | CAP # 100nF 16V 0603 | 2 | 10
CAP # 1uF 16V 0603 | C5, C6 | CAP # 1uF 16V 0603 | 2 | 10
CAP # 100pF 50V 0603 | C22 | CAP # 100pF 50V 0603 | 1 | 5
SW # CZ20 2x4 | CZ1 | SW # CZ20 2x4 | 1 | 5
LED # RGB WS2812C-5050 | D1, D2, D3, D4, D5, D6, D7, D8 | LED # RGB WS2812C-5050 WH | 8 | 40
Schottky # SS24-MS | D9 | Schottky # SS24-MS | 1 | 5
USB # C 2.0 RCPT TYPEC-304S-ACP16 | J1 | USB # C 2.0 RCPT TYPEC-304S-ACP16 | 1 | 5
2.54mm dual row 12way | P1 | Pin Header 2.54mm dual row 12way | 1 | 5
Pin Header 2.54mm 3way | P2, P3 | Pin Header 2.54mm 3way | 2 | 10
RES VAR POT 10k RK09K1130AAU | R1, R2, R4, R5, R12, R13 | RES VAR POT 10k RK09K1130AAU | 6 | 30
RES VAR SLIDE 50k RS301111J00R | R3, R6, R14 | RES VAR SLIDE 50k RS301111J00R | 3 | 15
RES # 10K 0603 | R7, R15, R16, R17, R18, R20, R22, R24 | RES # 10K 0603 | 8 | 40
RES # 0R 0603 | R8, R9 | RES # 0R 0603 | 2 | 10
RES # 5K1 0603 | R10, R11 | RES # 5K1 0603 | 2 | 10
RES # 1K 0603 | R19, R21, R23, R25 | RES # 1K 0603 | 4 | 20
SW # TACT small 4.5x4.5mm SMD WS-TASV | SW2 | SW # TACT small 4.5x4.5mm SMD WS-TASV | 1 | 5
SL2301 # P-Ch MOSFET -2.3A -20Vds | T1 | SL2301 # P-Ch MOSFET -2.3A -20Vds | 1 | 5
OP # LM324 | U1 | OP # LM324 | 1 | 5
LDO # 3V3 300mA RT9078-33GJ5 | U2 | LDO # 3V3 300mA RT9078-33GJ5 | 1 | 5
RISCV # CH32X035G8U6 | U6 | RISCV # CH32X035G8U6 | 1 | 5

TOF-ADDON 2026 REV.00

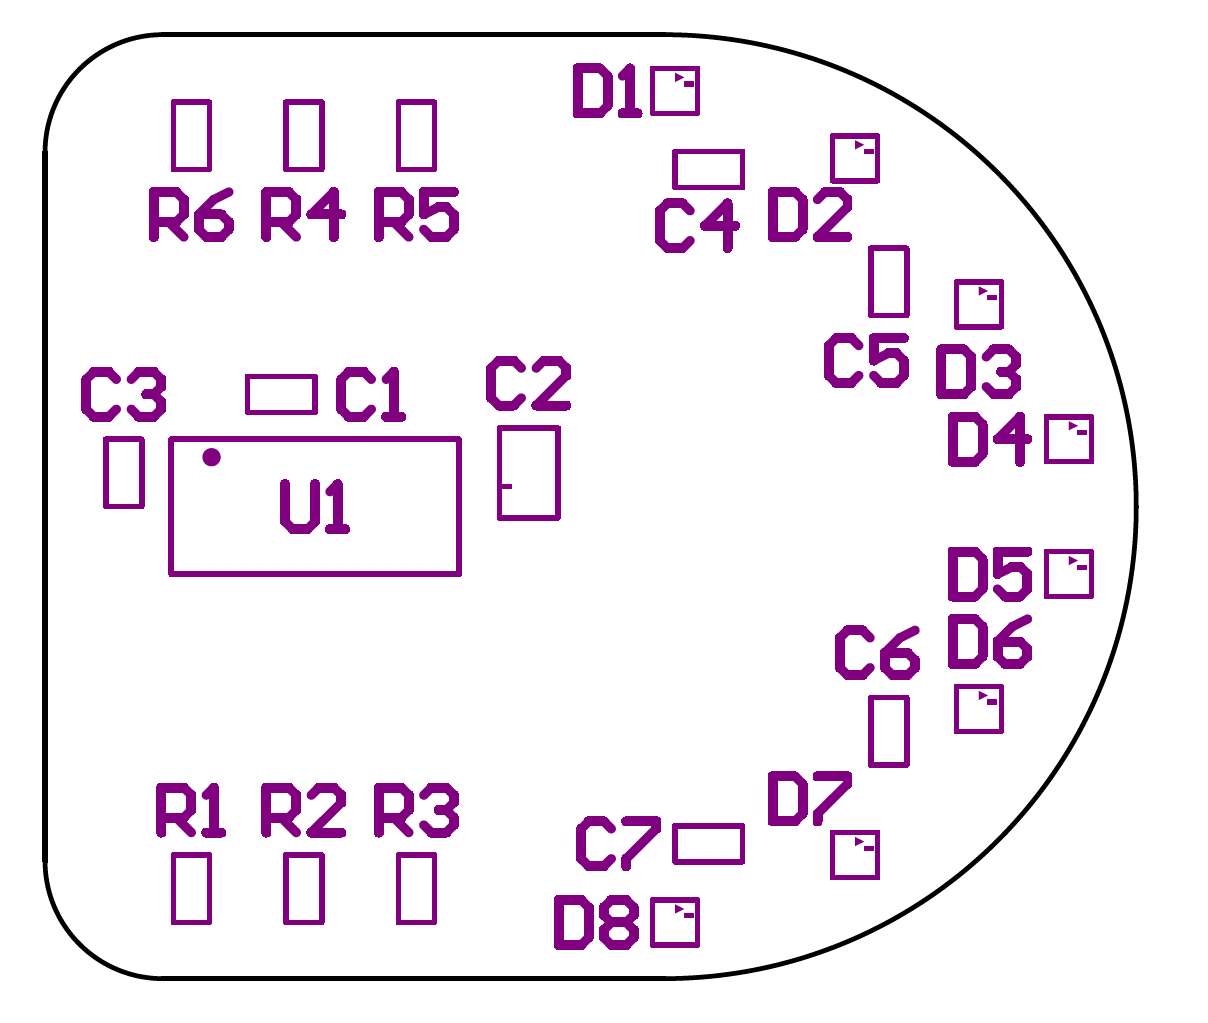
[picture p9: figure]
Afbeelding met tekst, Lettertype, diagram, schermopname Door AI gegenereerde inhoud is mogelijk onjuist.

LibRef | Designator | Description | QTY | 9
CAP # 100nF 16V 0603 | C1, C3, C4, C5, C6, C7 | CAP # 100nF 16V 0603 | 6 | 54
CAP # 10uF 10V 0805 | C2 | CAP # 10uF 10V 0805 | 1 | 9
LED # RGB XL-1010RGBC-WS2812B | D1, D2, D3, D4, D5, D6, D7, D8 | LED # RGB XL-1010RGBC-WS2812B | 8 | 72
Header dual row 6way Boxed | P1 | Header 2.54mm dual row 6 Boxed | 1 | 9
RES # 47K 0603 | R1, R4, R5, R6 | RES # 47K 0603 | 4 | 36
TOF # VL53L7CH | U1 | TOF # VL53L7CH | 1 | 9

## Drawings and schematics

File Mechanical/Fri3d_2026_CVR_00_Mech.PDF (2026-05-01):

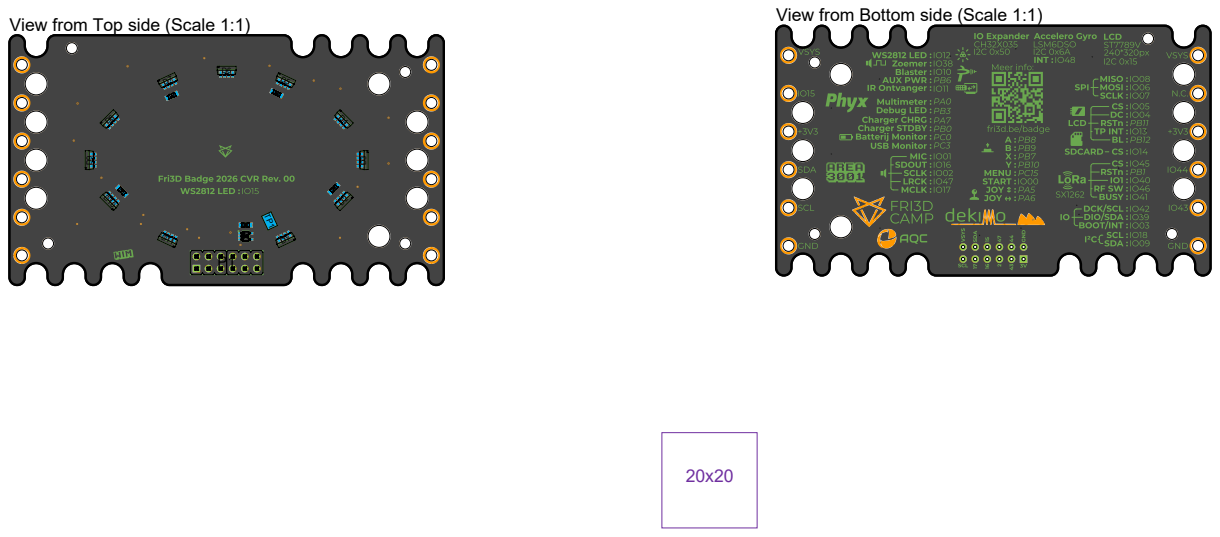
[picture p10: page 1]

View from Bottom side (Scale 1:1)

View from Top side (Scale 1:1)

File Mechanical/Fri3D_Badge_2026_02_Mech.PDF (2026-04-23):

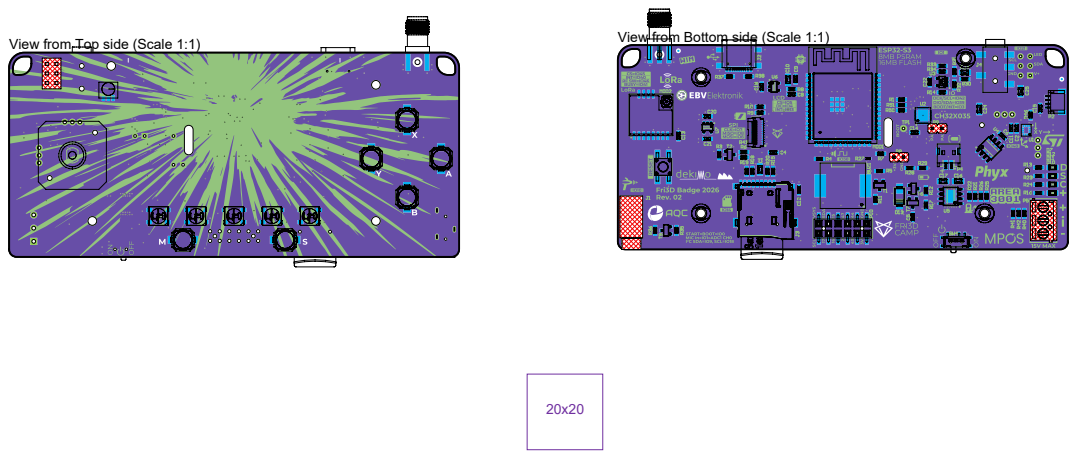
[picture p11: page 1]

View from Top side (Scale 1:1)

View from Bottom side (Scale 1:1)

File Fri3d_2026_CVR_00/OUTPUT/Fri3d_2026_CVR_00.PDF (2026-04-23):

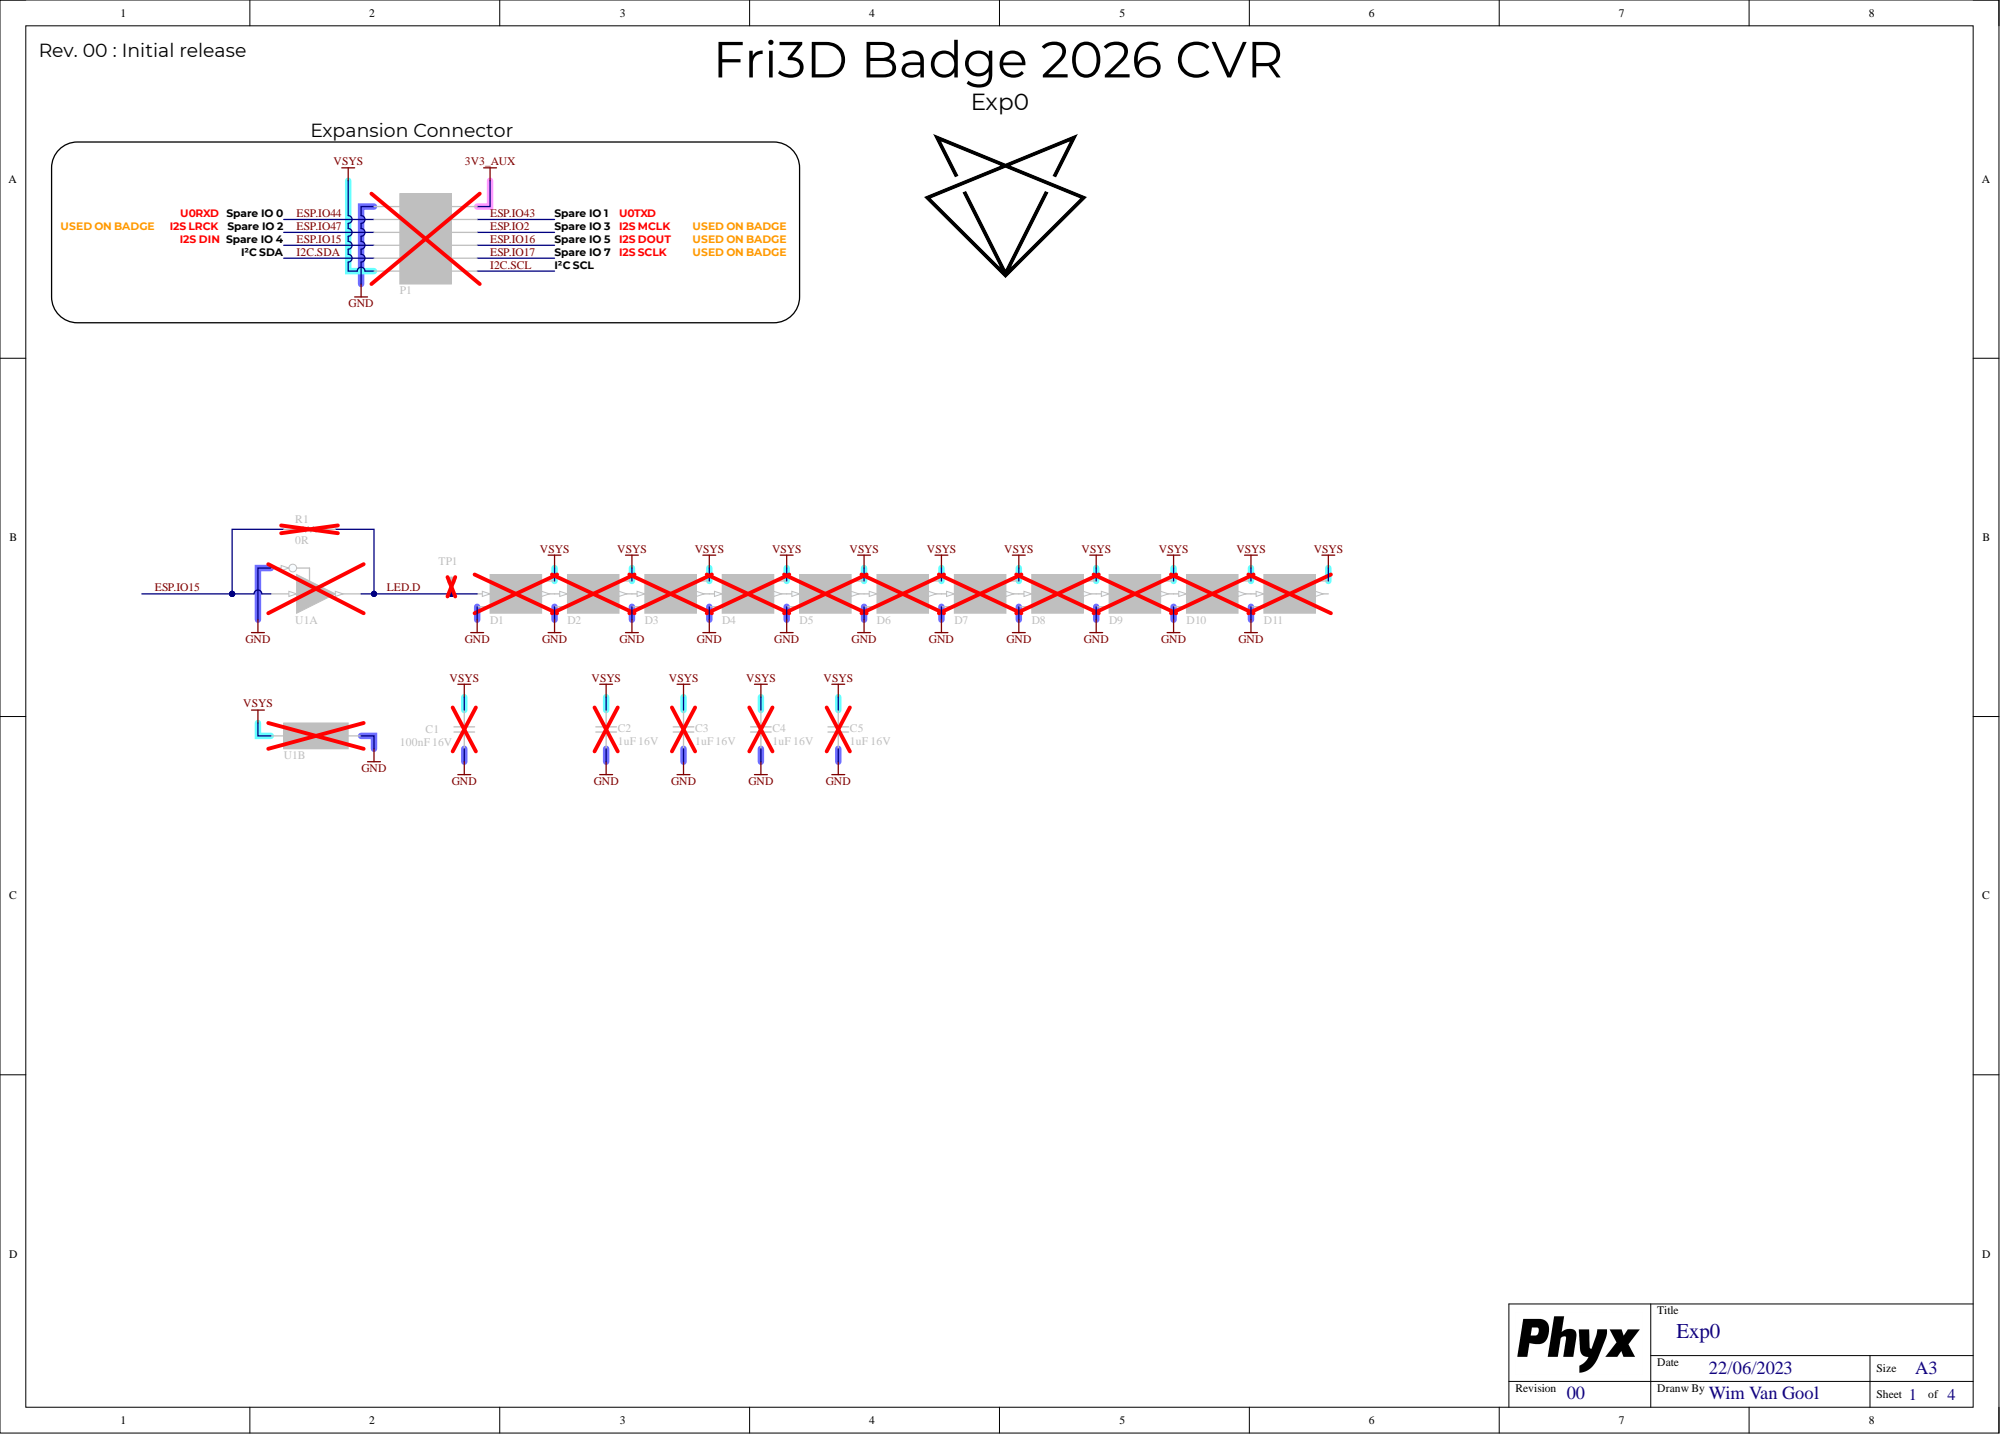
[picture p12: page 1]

Fri3D Badge 2026 CVR Rev. 00 : Initial release

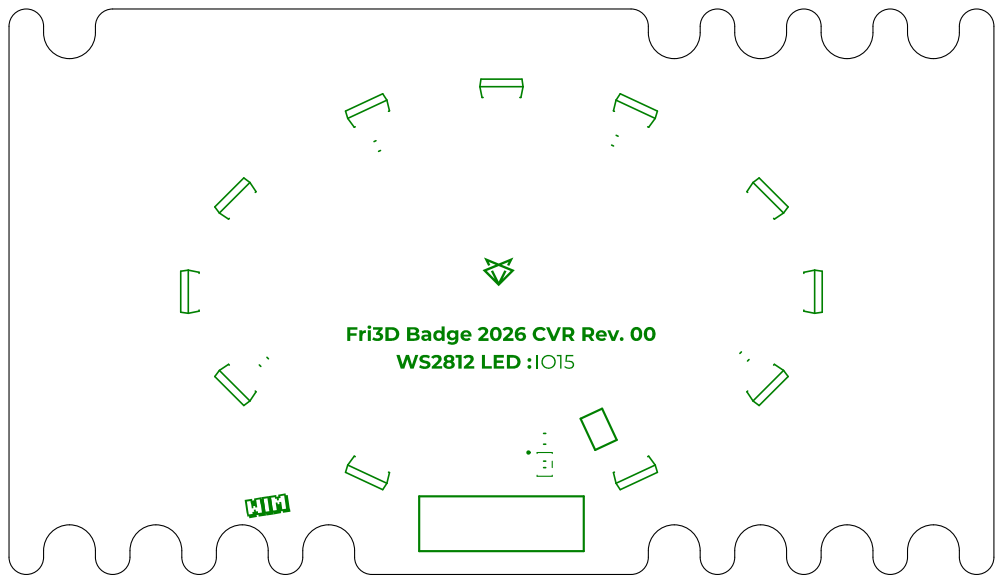
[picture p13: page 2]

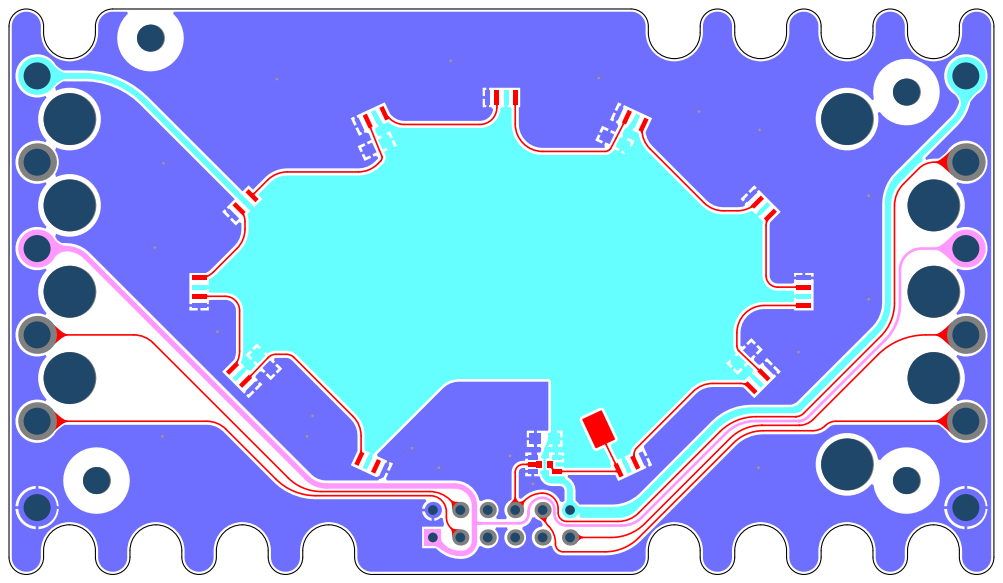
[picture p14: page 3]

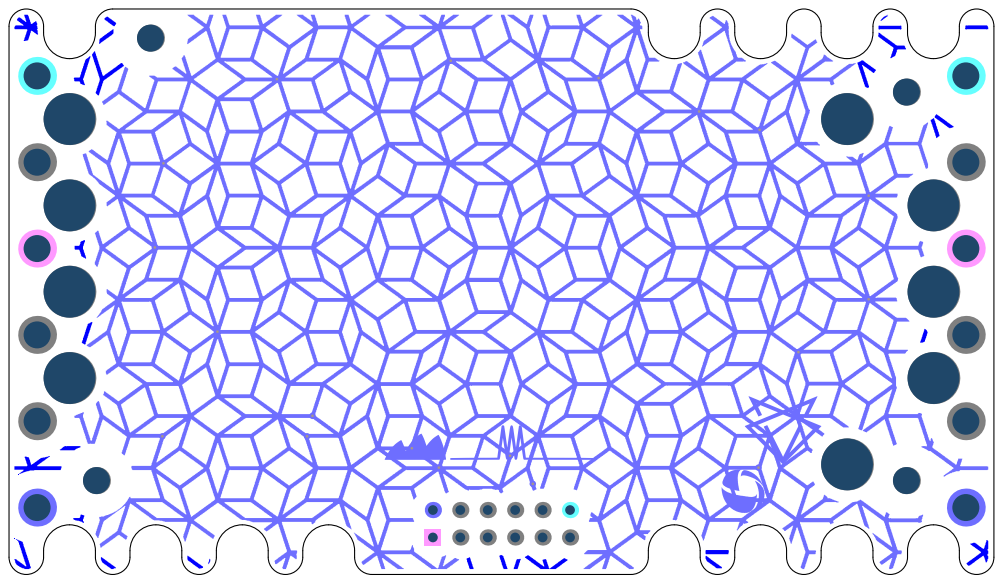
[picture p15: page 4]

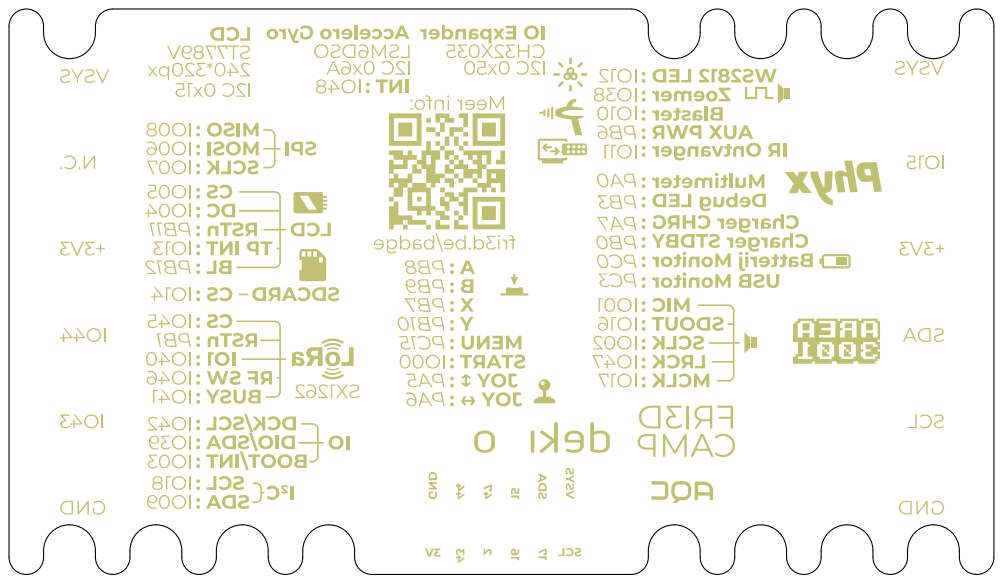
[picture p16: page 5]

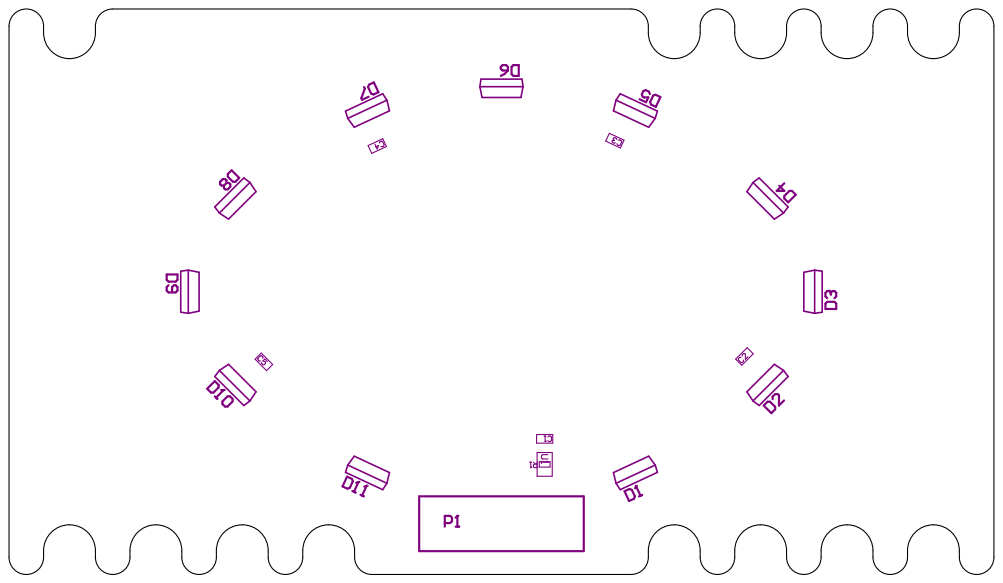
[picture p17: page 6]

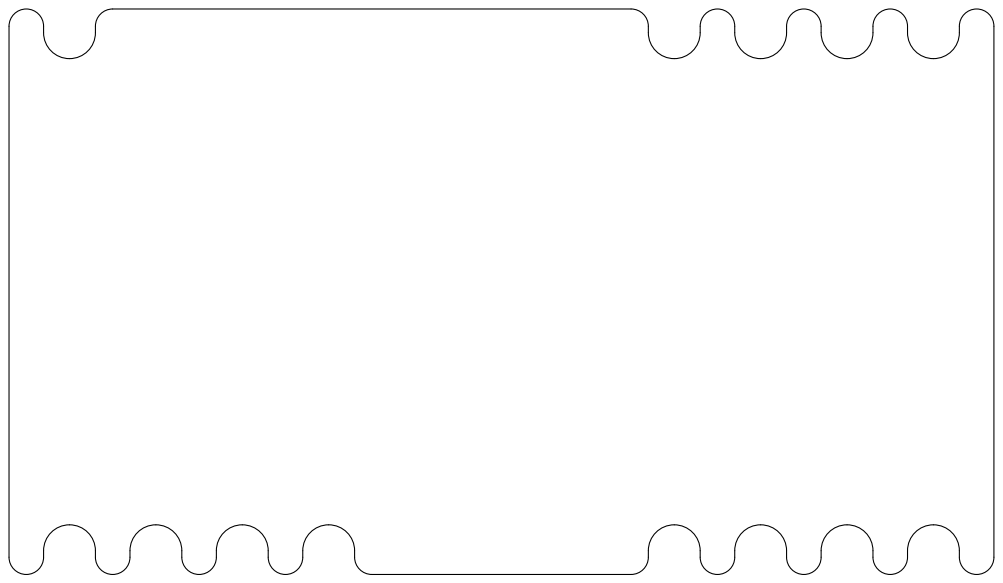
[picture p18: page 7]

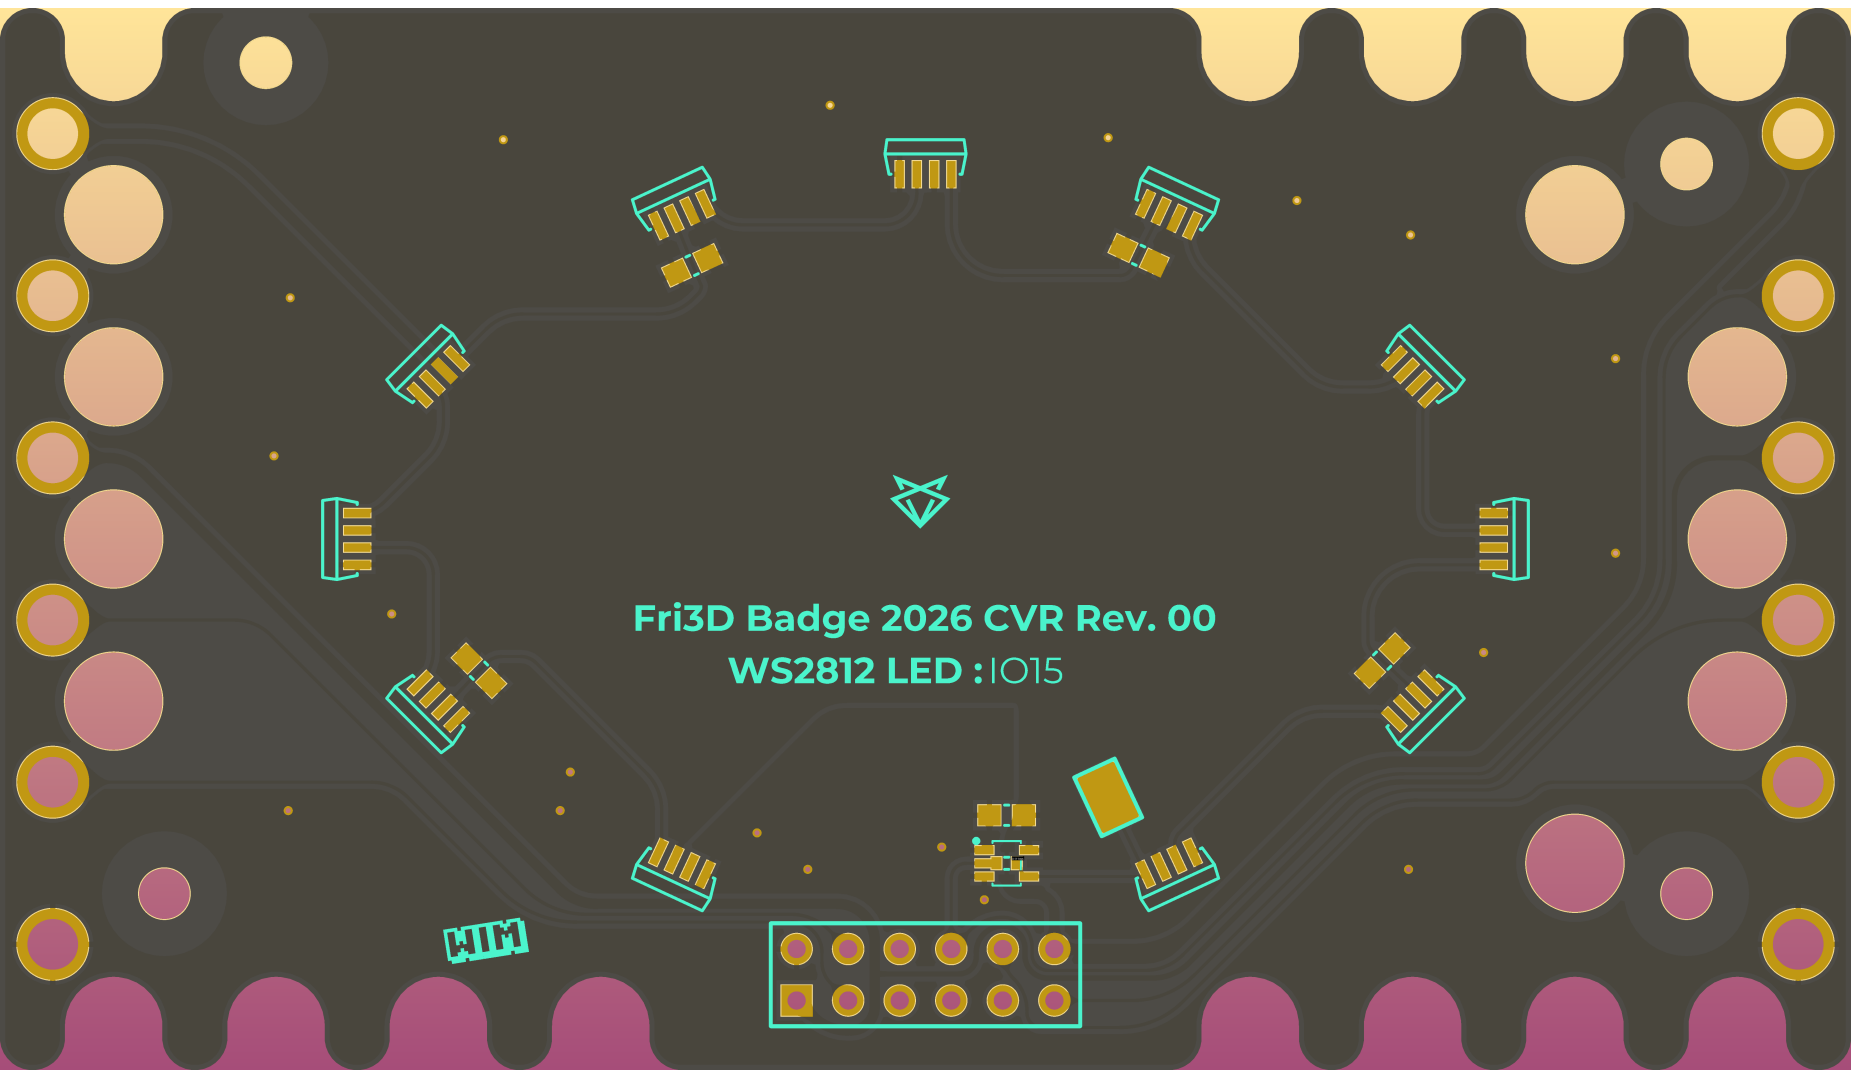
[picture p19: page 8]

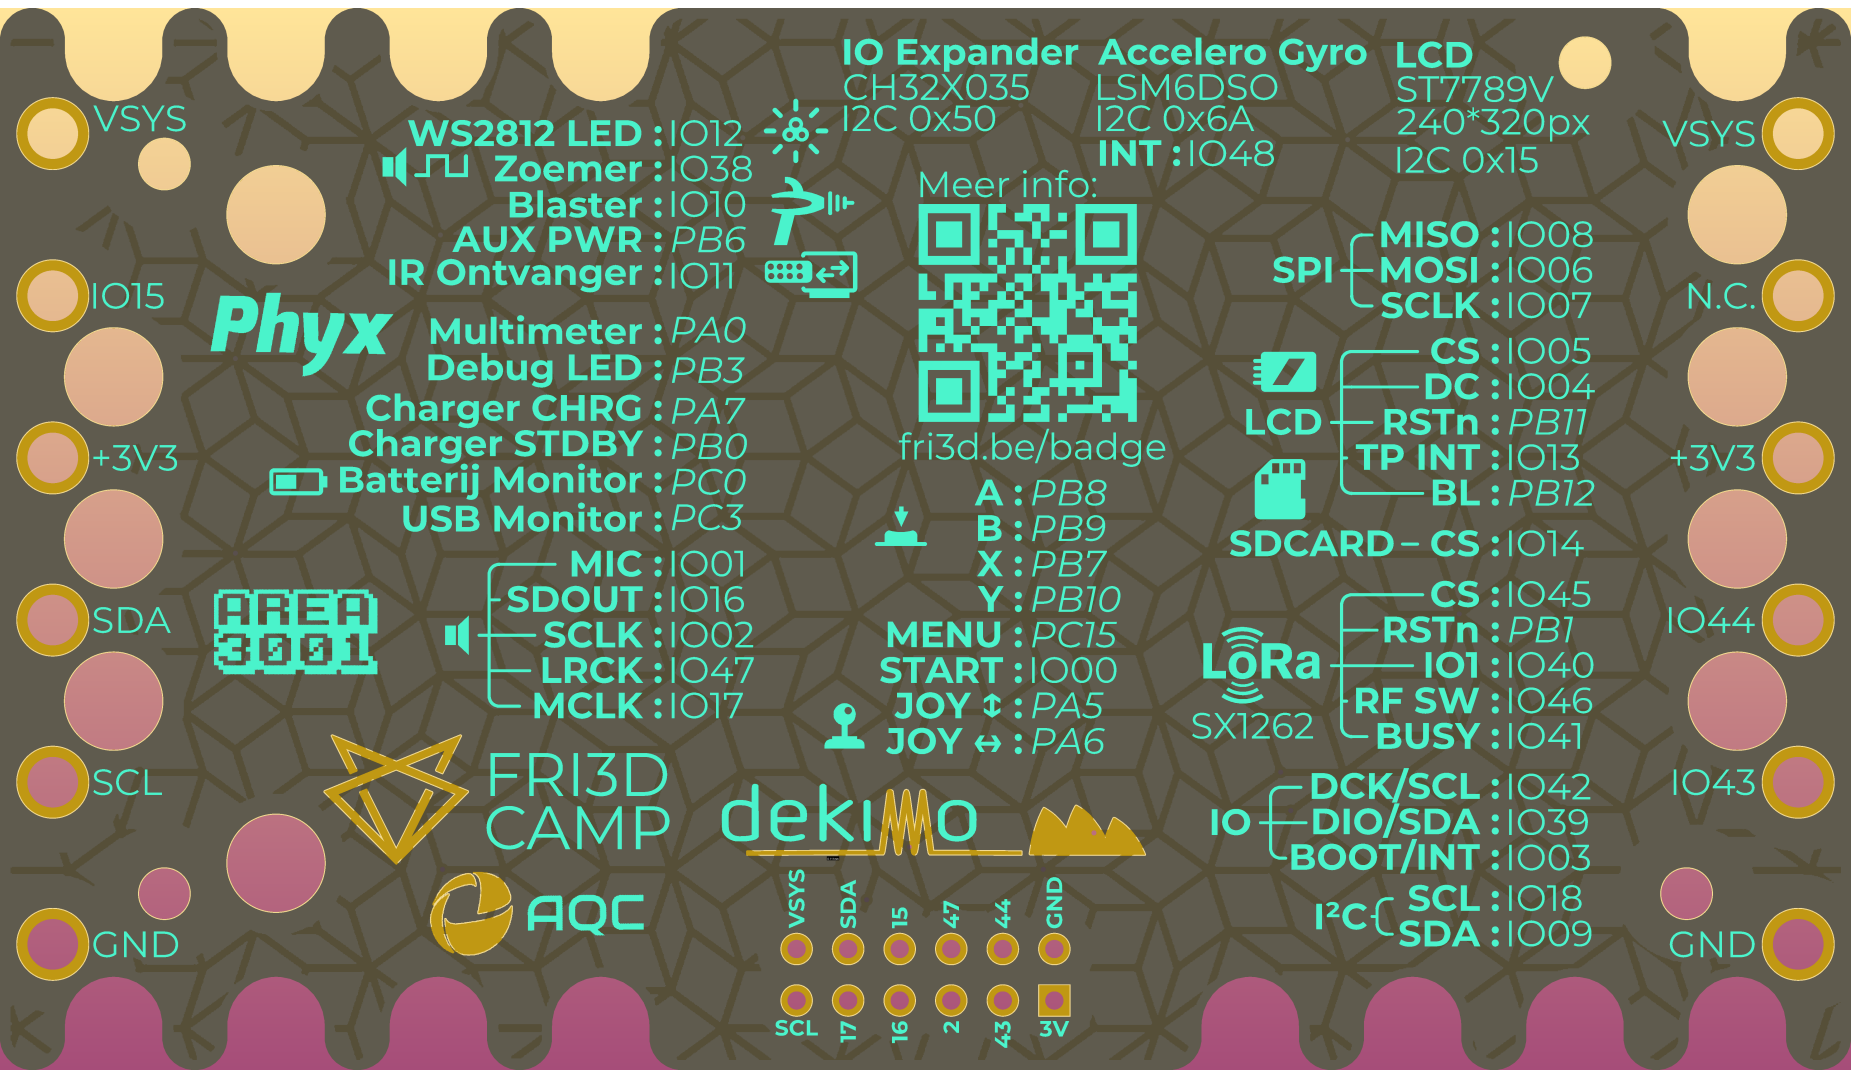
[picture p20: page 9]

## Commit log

2026-04-23 initial commit
    Commit all hardware revision.
    [Bill of Materials-Fri3D_2026_00(Default).xls, Bill of Materials-Fri3D_2026_01(Default).xls, Bill of Materials-Fri3D_2026_02(Default).xls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]
2026-05-01 Updated 3D and 2D Mechanical files
    [Fri3d_2026_CVR_00.step]
2026-05-01 renamed the "3D" folder to "Mechanical"
    [Fri3d_2026_CVR_00.step, joystick.stl]
